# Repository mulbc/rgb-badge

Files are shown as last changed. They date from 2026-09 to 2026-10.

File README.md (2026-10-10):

<!-- SPDX-License-Identifier: CERN-OHL-S-2.0 -->

# RGB Badge

An open-source, full-colour wearable LED badge inspired by the FOSSASIA Badge Magic form factor.

The project is currently in **draft schematic development**. Several coupon circuits are captured, including a provisional charger core, but the complete power circuit and PCB are unfinished. No board in this repository has been independently reviewed, fabricated or tested. Do not treat current design material as production-ready.

## Product target

| Property | Target |
|---|---:|
| Display | 48 × 16 individually controlled RGB pixels |
| Pixel pitch | 1.95 mm |
| Finished envelope | ≤110 × 35 × 11 mm |
| Finished weight | ≤75 g target; 100 g absolute maximum |
| Reference runtime | Approximately 6 h at the defined mixed-content workload and fixed indoor brightness |
| Charging/data | USB-C, 5 V, A-to-C and C-to-C; native USB data |
| Wireless | BLE enabled only in programming mode |
| Controller | ESP32-S3-WROOM-1U-N16R8 |
| Manufacturing | Turnkey PCBA; no hand assembly of SMT parts |

Six hours is not a maximum-brightness guarantee. The initial model predicts about 6.3 hours with a 900 mAh cell for the reference workload and about 1.1 hours for continuous maximum full-screen white. Coupon measurements will replace those estimates.

## Development strategy

The first physical board is a production-intent 16 × 16 coupon. It compares Everlight `EAST10105RGBA0` 1010 and QT Brightek `QBLP1515A-RGB2A` 1515 common-anode RGB LEDs while exercising the intended controller, matrix driver, USB-C, charger, battery gauge, power converters, antenna and controls. The full 48 × 16 badge will not be ordered until the coupon passes its electrical, optical, thermal, runtime and RF acceptance tests.

Start with:

1. [Project context](CONTEXT.md)
2. [Requirements](docs/requirements.md)
3. [Full project plan](docs/project-plan.md)
4. [Accepted decisions](docs/decisions/README.md)
5. [Coupon core component candidates](docs/sourcing/coupon-rev-a-core-candidates.md)
6. [Contributor and agent rules](AGENTS.md)

## Repository layout

| Path | Contents |
|---|---|
| `docs/` | Requirements, decisions, project plan, bring-up and test evidence |
| `hardware/` | Editable KiCad projects and project-local libraries |
| `firmware/` | ESP-IDF firmware and host-side tests |
| `mechanical/` | Parametric enclosure source and reviewed exports |
| `manufacturing/` | Immutable, revisioned fabrication and assembly releases |
| `tools/` | Asset compiler, validation and release tooling |

## Safety and verification

This project contains a rechargeable lithium-polymer cell and switching power electronics. A completed coupon schematic and preliminary PCB layout must be reviewed by an experienced hardware engineer before fabrication. Battery charge limits may only be changed after checking the exact terminated-pack specification. Test results must always identify the board revision and must never be inferred or fabricated.

## Attribution

The project uses the [FOSSASIA Badge Magic hardware](https://github.com/fossasia/badgemagic-hardware) as an attributed reference. It is a new design rather than a copy of that PCB. See [NOTICE](NOTICE).

## Licensing

- Hardware design files, mechanical design files, manufacturing files and hardware documentation: [CERN-OHL-S-2.0](LICENSES/CERN-OHL-S-2.0.txt).
- Firmware, scripts and software tooling: [Apache-2.0](LICENSES/Apache-2.0.txt).
- Third-party files retain their original licences and must be recorded before inclusion.

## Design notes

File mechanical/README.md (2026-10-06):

<!-- SPDX-License-Identifier: CERN-OHL-S-2.0 -->

# Mechanical design

The enclosure will be parameterized in CadQuery and released as source plus reviewed STEP/STL exports. It must enforce the finished envelope, protect the pouch cell, reserve the RF zone and support a replaceable development diffuser.

Do not freeze the 900 mAh cell or final enclosure until a complete PCB STEP assembly proves the thickness stack without pouch compression.

The [2026-09-26 envelope screen](envelope-screen-2026-09-26.md) quantifies display width and a trial 11 mm thickness stack. It flags conflicting manufacturer length figures for the 900 mAh *bare* cell. Under [ADR 0019](../docs/decisions/0019-board-mounted-battery-temperature-sensing.md), a protected two-wire pack with a battery-facing PCB NTC is now allowed for testing; no final pack or physical fit is selected.

The [USB/LED edge screen](usb-led-edge-screen-2026-09-26.md) finds a nominal 0.025 mm copper intrusion into the USB cutout guide with the centred final LED grid and 106 mm board, and flags the connector's 0.80 mm board recommendation against the historical 1.0 mm plan. Actual placement and stack-up remain to be qualified.

The [preliminary front/rear placement study](preliminary-placement-screen-2026-09-26.md) additionally checks exact LED/USB courtyards. A centred grid conflicts with the USB courtyard; an illustrative 1.775 mm left shift avoids *bounding-box* intersections but does not establish manufacturability. The trial rear placement omits many components and the final battery.

The [2026-10-06 board/battery fit trial](fit-trial-2026-10-06.md) adds a grouped rear footprint plan and an 11 mm section with a separate LP503055 pack that still needs support above the board. All 32 row switches and 77 conditional under-pack 0402 candidates have nonoverlapping XY trial positions, but eight captured coupon parts and all remaining power/connector/RF/mounting needs are unplaced. A 0.55 mm 0402 height example leaves only 0.25 mm nominal case margin before assembly tolerances. No physical mount, complete PCB or DRC has been validated.

The [battery-connector screen](battery-connector-screen-2026-10-06.md) compares JST GH/PH and Molex PicoBlade families for the LP503055's bare AWG 28 wires. An illustrative PH mated pocket has no free position in the original grouped plan, even before small-part packing. No pack termination or polarity has been selected.

The [connector-first follow-on](connector-first-trial-2026-10-06.md) adds a compact Molex PicoBlade candidate and moves the switch, decoder and row FETs around its illustrative 8 × 8 mm pocket. It leaves 11 captured parts unplaced before the missing power hardware. The added connector is a geometric reservation, not a qualified footprint or selected pack termination.

The [dual-row package screen](dual-row-package-screen-2026-10-06.md) evaluates one complementary N/P MOSFET package per row under [proposed ADR 0020](../docs/decisions/0020-dual-row-mosfet-package-proposal.md). Its current XY trial accommodates the retained non-row captured parts, four power-IC package minima and the staged VLED passives; ADR 0021 removes the on-board battery-current monitor. Other support circuits, routing, copper and assembly clearances remain. It is not a complete PCB fit or an approved row-circuit change.

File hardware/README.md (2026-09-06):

<!-- SPDX-License-Identifier: CERN-OHL-S-2.0 -->

# Hardware

Editable KiCad electronics live here. Each revision is self-contained and must include project-local symbols, footprints and 3D models plus a README identifying its status and evidence.

The authoring baseline is KiCad 10.0.6 under [ADR 0006](../docs/decisions/0006-kicad-10-workflow.md). Use only validated stable `10.0.x` releases for canonical files; do not save them with a testing, nightly or newer major build.

Each revision will use this structure when capture begins:

```text
<revision>/
├── <project>.kicad_pro
├── <project>.kicad_sch
├── <project>.kicad_pcb
├── sym-lib-table
├── fp-lib-table
├── symbols/
├── footprints/<project>.pretty/
└── 3dmodels/
```

Before committing an exact part, compare symbol pin numbers, exposed pads, footprint geometry, courtyard, polarity/orientation marks and tape orientation with the current manufacturer documentation. Imported library models are starting material, not evidence of correctness.

No hardware design has been fabricated yet.

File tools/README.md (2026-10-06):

<!-- SPDX-License-Identifier: Apache-2.0 -->

# Software tools

The unlinked VLED converter is generated by tools/generate-coupon-vled.py and independently checked with native KiCad XML/ERC by tools/check-coupon-vled.py. The isolated sheet intentionally reports two missing source drivers; protected SYS and the display interlock are not captured.

`python3 tools/screen-preliminary-placement.py --output mechanical/review` reads four project-local footprint courtyards plus the USB cutout guide and regenerates the [final-badge bounding-box screen](../mechanical/preliminary-placement-screen-2026-09-26.md). It produces an SVG and JSON, **not** a KiCad PCB or DRC clearance. Its 700 mAh pack rectangle is a coupon-only mechanical comparison; no battery has been selected for the final badge.

**Current staged-gauge checkpoint — ADR 0015:** `generate-coupon-gauge.py --output NEW_DIRECTORY` produces the gauge/bypass/two pull-ups and a flagged **assumed** switched battery boundary without replacing canonical source. `check-coupon-gauge.py` checks exact part metadata and source pin nets; the complete KiCad XML check now expects **400 on-board items and 1,507 logical pins**, including the new alert no-connect. Native KiCad review is pending, and no physical battery, charger or latching switch is captured. [Boundary record](../hardware/coupon/rev-a/switch-gauge-boundary.md). The previous ADR 0013 Type-C-only checkpoint had 396 items / 1,492 pins; its 16-state permission and independent gate checks still run. Older dual-limit/BC1.2 calculations are historical.

`generate-coupon-permission.py --output NEW_DIRECTORY` produces the conditioning and permission sheets without overwriting canonical files. `check-coupon-permission.py` traces 61 items / 176 pins and evaluates actual gate connections against the independent 1,024-state contract. This checkpoint passed native review at `6d9a08b`.

`generate-coupon-usb.py --output NEW_DIRECTORY` produces the USB interface sheet. `check-coupon-usb.py` checks its 20 items / 84 logical pins and domain/data connections. The added logic supervisor brings complete XML validation to **443 items / 1,636 logical pins**. Native review at [2bb0e08](../docs/development/logic-supervisor-review-2bb0e08.md) passed zero ERC violations and the eleven-page export. The precision-resistor increment added three ERA2 symbols and one footprint. The subsequent candidate ADG4612 library brings exports to **46 symbols and 27 footprints per raw view**; its [native rendering at 2b7a468](../docs/development/actuator-library-review-2b7a468.md) passed. Its [native rendering at 9e71bb5](../docs/development/precision-resistor-review-9e71bb5.md) passed; older counts below are historical.

`check-programming-resistors.py` validates the exact ADR 0012 symbols, ERA2 lands/courtyard and conditional multiplicative error budget. The existing current ceilings retain ±1% total resistance error. The assembly/service drift allocation, switch leakage and complete USB-current budget remain qualification items. `check-kicad.sh` requires each new native export; test fixtures only exercise wrapper behavior.

The [permission-library audit](../hardware/coupon/rev-a/permission-library-audit.md) covers the six new exact gate/supervisor symbols and shared DBV5/DBV6 package checks. `check-power-libraries.py` now guards ground-pin differences, open-drain electrical types, output polarity, package body/courtyard geometry and DBV6 mask/paste settings. Native permission-library rendering passed at `6d9a08b`; TPS3808 is now captured as U34 and passed native review at 2bb0e08.

Host-side utilities will include the deterministic content compiler, schema validation, release-manifest generation and analysis of power/runtime logs. Tools must be testable without a connected badge and must not rewrite measured evidence.

`check-led-libraries.py` audits the exact Coupon Rev A LED symbol pin maps, source drawing layout, footprint pads, polarity geometry and the nominal 1.95 mm checkerboard-clearance calculation. `check-kicad.sh` runs that audit, loads and exports the project-local libraries through KiCad 10, and runs schematic ERC. `check-erc-report.py` requires zero ERC messages; the historical `USB_D-` / `USB_D+` boundary exceptions are retired. Raw fabrication views and solid copper-only views are exported into separate directories.

`number-footprint-review.py SOURCE.svg NEW_OUTPUT.svg` creates a separate numbered review copy of a four-pad KiCad 10 fabrication export. It overlays KiCad's own glyph paths on white halos so body lines do not obscure the pad numbers. It preserves source evidence and geometry, adds a viewing margin, records the source SHA-256, and fails if the expected label structure changes. With `--profile rpw`, it requires the exact 14-glyph/10-pad multiplicities, removes numeric glyphs only from the derived copy and overlays the first unchanged source glyph per pad. This resolves repeated corner numbers on the compound RPW lands without moving geometry. The wrapper places these derived files in `footprints/numbered/`; they are not manufacturing outputs. The [recorded review](../docs/development/led-library-review-27c01b4.md) used the owner's actual KiCad exports.

`check-coupon-matrix.py` checks the matrix source: it verifies cached symbols, traces short wires to global labels, and checks all 256 LEDs and 1,024 pin-to-net assignments. This source subset checker is not KiCad ERC and does not support arbitrary buses, rotations or mid-wire junctions. Its historical `--netlist` mode remains available for matrix-only fixtures; the controller checker now owns complete native XML validation. `check-kicad.sh` runs every source checker around the real KiCad ERC/netlist export and also exports `coupon-schematic.pdf`.

`generate-coupon-matrix.py --output NEW_DIRECTORY` reproduces the initial matrix capture with stable UUIDs. It writes only a new directory and refuses existing paths. The generated draft was reviewed before its files were copied into the canonical project. Do not regenerate over subsequent KiCad edits; compare a temporary regeneration and integrate deliberate changes. Schematic orientation does not set PCB placement rotation.

Run the wrapper regression tests without KiCad:

```bash
python3 -m unittest discover -s tools/tests -p 'test_*.py' -v
```

The wrapper tests use a stub executable to check CLI arguments, output separation and failure handling. SVG-helper tests check original-geometry and glyph preservation, rejection of missing/duplicate/transformed labels, and protection against overwriting evidence. They do not render KiCad files, run real ERC, prove legibility or approve hardware. Actual KiCad output and human inspection remain required.

Matrix regression tests deliberately inject a colour swap with unchanged net sizes, a missing LED, a short between columns, a duplicated pin, a wire endpoint that misses its LED pin, and a global label facing into its wire. The label-direction check came from actual PDF review at `7120e93`. Synthetic XML tests prove checker behaviour; only a real KiCad-exported netlist can verify KiCad's interpretation of the new schematic.

## Driver increment

`python3 tools/check-coupon-driver.py` checks the controlled driver/support library, footprint geometry and simple source wiring. Its `--netlist` mode preserves the historical matrix-plus-driver 1,094-pin contract for regression evidence. The full current project must use `check-kicad.sh`, which delegates the complete XML to the row checker.

`python3 tools/check-row-libraries.py` independently checks the exact row decoder, P/N MOSFET and 1 kΩ pull-up symbols against their manufacturer pin tables, plus the TSSOP24, SC-59 and SOT23 pad geometry.

`python3 tools/check-coupon-rows.py` traces the captured decoder, all sixteen P/N-MOS stages, 37 resistors, decoupling and draft VLED boundary. Its `--netlist` mode preserves the historical 335-item / 1,290-pin matrix + driver + row contract. `generate-coupon-rows.py --output NEW_DIRECTORY` deterministically reproduces the initial row sheet and refuses existing paths; never regenerate over canonical KiCad edits.

`python3 tools/check-controller-libraries.py` checks the exact N16R8 module symbol/pad map, reset/USB/UART passives, capacitor lands and duplicate-contact mode-button footprint. `python3 tools/check-coupon-controller.py` traces the controller source and explicit no-connects; its `--netlist` mode owns the complete current contract; the original controller-stage contract was 356 items / 1,360 logical pins. `generate-coupon-controller.py --output NEW_DIRECTORY` deterministically reproduces the initial controller sheet and refuses existing paths.

The wrapper exports all project-local symbols and footprints, including separate paste views, and requires their files to be nonempty. `coupon-matrix.xml` retains its historical filename but contains the whole captured schematic. Local fixture tests do not run KiCad. Follow the [controller review instructions](../hardware/coupon/rev-a/controller-capture.md#native-review-still-required) for the current eight-page circuit.

`generate-coupon-matrix.py` is the historical one-time matrix-only capture helper. It must not replace the current root schematic: that would remove the driver sheet. The current KiCad files are canonical.

## Power pre-capture

`python3 tools/check-usb-connector.py` checks the GCT USB4505 candidate's 16-contact/12-land mapping, four plated shell-slot interpretations, 0.20 mm nominal copper clearance and non-manufacturing cutout datums. `check-kicad.sh` also exports a separate `footprints/mechanical/` view. See the [connector audit](../hardware/coupon/rev-a/usb-connector-audit.md) for source evidence, native review status and the unresolved cutout relief/process limits. The connector is not yet instantiated.

`python3 tools/check-power-design.py` freezes the selected BQ24074 `ISET`/external-`ILIM` arithmetic, ADR 0010 source/switch/configuration/suspend state table, initial TPS631000/TPS63020 feedback dividers, and maximum charger-plus-gauge allocation within the 50 uA OFF-state budget. It deliberately does not approve the captured BQ24392/TS3USB31E/priority logic as a complete power system, VBUS auxiliary-current budget, pack-dependent NTC/current limit, linear thermal behavior, converter passives or layout. See the [power/input pre-capture record](../hardware/coupon/rev-a/power-pre-capture.md).

`python3 tools/check-power-libraries.py` checks the selected `BQ24074RGTR`, `BQ24392RSER`, `TS3USB31ERSER`, legacy `BQ25616JRTWT`, `TPS631000DRLR`, `TPS63020DSJT`, `TLV75533PDBVR`, `SN74LVC1G04DBVR`, `MAX17048G+T10`, `INA232AIDDFR`, base-suffix `TPD4E05U06DQAR` and `TUSB320LAIRWBR` symbols against manufacturer pin tables. It verifies every RGT/RSE/RTW/DRL/DSJ/DBV/DDF/DQA/RWB/T822+3 land, exposed-pad splits, the RWB side-pad copper/paste difference, layers and pin-1 marks. The [power-library audit](../hardware/coupon/rev-a/power-library-audit.md) records source hashes and the intentionally unresolved connector/control packages. `check-kicad.sh` requires nonempty native symbol plus fabrication/copper/paste exports for every new footprint; the selected replacement libraries passed [native render review at c054cb4](../docs/development/power-replacement-review-c054cb4.md). Their [audit](../hardware/coupon/rev-a/power-replacement-library-audit.md) records the narrower RSE middle pads, 0.05-mm radii, body axes and corresponding fault tests.

`python3 tools/check-usb-permission.py` checks ADR 0011's detector GPIO contract over 1,024 stable input combinations, including hardware-only resistor boost and default-deny supply/reset behavior. This is a static contract, not a captured or simulated gate circuit. The power arithmetic check reserves configured-SDP auxiliary headroom, rejects the historical fixed-USB500 budget and prints the remaining capture blockers explicitly. Run `python3 tools/check-power-design.py --require-usb-closure` to require an implemented USB topology: it still exits 1 by design until protected input, supervisors, charger/ILIM actuation and complete power qualification are finished. State-table or library success alone is not USB-current closure. The rejected BQ25616J arithmetic remains as regression evidence.

## Logic-rail supervision checkpoint

`check-usb-supervision.py` audits the TPS3808 divider/CT selection and exact 620 kohm resistor. It is called by the permission capture check. Source totals are now 443 items / 1,636 logical pins on eleven pages. The native d502e65 bundle passed ERC/XML; its two heading findings and the added supervisor passed native review at 2bb0e08. See [capture and limits](../hardware/coupon/rev-a/usb-supervision-capture.md). The ordinary-resistor temperature counterexample remains regression evidence; ADR 0012 precision selection addresses it conditionally, with assembly/service drift still requiring qualification.

`check-power-design.py` also reports the candidate actuator shared-rail static UVLO margin. `actuator_supply_screen()` accepts explicit hypothetical local-drop/slew/delay bounds; it is a sensitivity calculation, not a transient guarantee. See the [supply analysis](../hardware/coupon/rev-a/charger-actuator-supply-analysis.md).

## Input protection screening

`python3 tools/check-input-protection.py` calculates candidate OVLO and PGTH divider corners with signed leakage and total resistor error, and records fixed-clamp/current-threshold limitations. It does not select a protection IC or validate transients. `--require-closure` deliberately fails until the input circuit is qualified. See ADR 0014 and `hardware/coupon/rev-a/usb-input-protection-screening.md`.

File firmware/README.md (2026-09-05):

<!-- SPDX-License-Identifier: Apache-2.0 -->

# Firmware

Production firmware will use ESP-IDF and native C/C++. Initial scope is hardware validation: deterministic matrix scan timing, safe rail defaults, USB diagnostics, telemetry, test patterns, button state handling and a minimal BLE programming-mode transfer.

Host-test asset parsing, gamma conversion, frame scheduling and runtime-estimator maths before relying on target hardware. Do not create production drivers until exact devices and the machine-readable board pin map are frozen.

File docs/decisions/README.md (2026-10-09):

<!-- SPDX-License-Identifier: CERN-OHL-S-2.0 -->

# Architecture decision records

Decision records explain choices that materially constrain later work. Accepted records are not silently rewritten when a decision changes: add a superseding record and update the affected requirements and project context.

| ADR | Decision | Status |
|---|---|---|
| [0001](0001-coupon-first-development.md) | Validate a production-intent coupon before the full badge | Accepted |
| [0002](0002-discrete-multiplexed-rgb-matrix.md) | Use a discrete multiplexed RGB matrix | Accepted |
| [0003](0003-esp32-s3-module-and-external-antenna.md) | Use ESP32-S3 N16R8 with an external antenna | Accepted |
| [0004](0004-standalone-charging-and-hard-off-state.md) | Use standalone charging and switched application rails | Input-current proposal superseded by ADR 0009; functional requirements retained |
| [0005](0005-project-licensing.md) | Use CERN-OHL-S for hardware and Apache-2.0 for software | Accepted |
| [0006](0006-kicad-10-workflow.md) | Target KiCad 10 stable with controlled upgrades | Accepted |
| [0007](0007-coupon-led-finalist-pair.md) | Populate the coupon with two final-product LED candidates | Accepted |
| [0008](0008-qblp1515-checkerboard-placement.md) | Preserve the QBLP1515 land pattern with checkerboard rotation | Accepted |
| [0009](0009-usb-input-current-closure.md) | Reject unqualified direct USB input-current network | Accepted constraint; replacement selected by ADR 0010 |
| [0010](0010-source-qualified-off-charging.md) | Charge while OFF only from a qualified source | Accepted for capture; thermal/Gate A pending |
| [0011](0011-usb-total-current-headroom.md) | Reserve current for USB detection and permission logic | Accepted; resistor specification amended by ADR 0012 |
| [0012](0012-programming-resistor-error-budget.md) | Include temperature and drift in programming-resistor limits | Exact parts selected; assembly/service qualification pending |
| [0013](0013-type-c-only-fixed-current-charging.md) | Use Type-C-only charging with a fixed limit | Accepted for coupon capture; hardware verification pending |
| [0014](0014-usb-voltage-envelope-and-logic-ldo.md) | Correct USB voltage envelope and logic regulator | Draft circuit reviewed; input-stage qualification pending |
| [0015](0015-switch-fuel-gauge-with-application.md) | Disconnect the gauge with the physical switch | Accepted for coupon capture; exact switch and SOC recovery validation pending |
| [0016](0016-runtime-and-fit-over-charge-speed.md) | Prioritize badge runtime and fit over charging speed | Accepted; exact terminated pack and charge times pending |
| [0017](0017-parallel-3v3-converter-capacitors.md) | Parallel exact capacitors on the coupon application converter | Provisional coupon target; complete derating and rail qualification pending |
| [0018](0018-complete-power-architecture-proposal.md) | Review the complete power topology as one functional block | Proposed; six capture holds, no circuit changes |
| [0019](0019-board-mounted-battery-temperature-sensing.md) | Trial a board-mounted battery temperature sensor with protected two-wire packs | Accepted direction; cell-to-board thermal validation pending |
| [0020](0020-dual-row-mosfet-package-proposal.md) | Evaluate one complementary N/P package per row to recover PCB area | Proposed; no schematic or BOM change |
| [0021](0021-external-battery-current-measurement.md) | Measure battery current with an inline instrument during validation; omit the on-board monitor/shunt | Accepted for capture; instrument/harness and hardware validation pending |
| [0022](0022-lower-fixed-usb-input-limit-proposal.md) | Evaluate one existing 3.65 kΩ ILIM resistor to simplify charger/eFuse current coordination | Proposed; no schematic or BOM change |
| [0023](0023-charger-en2-local-clamp-proposal.md) | Feed charger EN2 from admitted input through a local 2.5 V clamp | Proposed; transient and EN2-load checks pending |
| [0024](0024-lp452845-pack-and-temperature-window.md) | Design Rev A around the exact protected LP452845/PHR-2 assembly with NTC and buffered hardware temperature inhibit | Accepted design target; source capture and physical qualification pending |

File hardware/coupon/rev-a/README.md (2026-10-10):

<!-- SPDX-License-Identifier: CERN-OHL-S-2.0 -->

# Coupon Rev A

**2026-10-06 VLED increment:** An [unlinked, default-disabled converter candidate](vled-converter-capture-contract.md) now captures the TI LED buck-boost, exact passives and local switching nodes. A separate [native local placement trial](staging/vled-layout-trial.kicad_pcb) carries the thirteen exact project footprints and schematic pad nets, with no routing or full-board DRC. It does not close the SYS source or display-interlock holds and is not a fabrication release.

**2026-10-10 power direction:** [Complete power system](../../../docs/design/power-architecture-2026-10-05.md), with [proposed ADR 0018](../../../docs/decisions/0018-complete-power-architecture-proposal.md), consolidates topology choices, budgets and six capture holds. [ADR 0024](../../../docs/decisions/0024-lp452845-pack-and-temperature-window.md) selects the exact protected `LP452845`/`PHR-2` finished assembly as the Rev A design target. The battery-facing NTC and separate TMP390 hot/cold hardware-inhibit subcircuit are now on a [root-linked sheet](charger-temperature.kicad_sch); its `CHARGER_TS` and `CHARGER_GATE_EN` nets await the BQ24074 and E1 connections. The pack connector is also not yet captured. Native KiCad exports can be run locally by the assistant.

The [TMP390 first-author library](tmp390-library-audit.md) maps the selected IC's six pins to a project-local DRL0006A footprint. The [connected temperature-sheet review](../../../docs/development/charger-temperature-capture-review-2026-10-10.md) records the source, native XML/ERC and visual checks. It does not demonstrate temperature protection on hardware.

The selected JST `S2B-PH-SM4-TB` board-header land is now staged in the [project-local footprint library](jst-ph-header-library-audit.md). Contact 1/2 and the retention lands are audited and rendered, but the header has no root schematic connection until the exact finished pack's lead polarity is reconciled with the mating view.

**Provisional application-power capture, 2026-10-05:** The [JS202011JCQN library audit](slide-switch-library-audit.md) now accompanies a root-linked control pole and the existing TPS631000 3.3 V converter candidate. The old `+3V3_APP` source flag is removed; the converter output is the schematic source. `+SYS_APP_IN_DRAFT` still has an explicit source flag because the charger/pack path is not captured. Switch pole 2 and the gauge source flag remain untouched pending bus isolation. JCQN is not yet the final top-edge mechanical selection. Native KiCad 10.0.6 ERC, complete XML and visual page review passed for the provisional sheets; no board or electrical hardware test exists.

**Active revision: [ADR 0013](../../../docs/decisions/0013-type-c-only-fixed-current-charging.md).** Type-C-only charging, one fixed current limit; no BC1.2 or firmware charge grants. The revised USB source has 396 total PCB items / 1,492 logical pins and eleven pages; [native ERC/XML and three-sheet visual review passed at 12a134f](../../../docs/development/type-c-only-review-12a134f.md). Libraries remain 46 symbols / 27 footprints. See [simplified capture](type-c-only-capture.md); earlier counts and source-policy descriptions below are historical.

**Follow-on draft:** [ADR 0014](../../../docs/decisions/0014-usb-voltage-envelope-and-logic-ldo.md) changes U29 to TPS70933DBVR and intentionally opens EN. Counts remain 396 items / 1,492 pins; libraries are now 47 symbols / 27 footprints. Native U29 review passed at bad43fa; see [evidence](../../../docs/development/input-review-bad43fa.md). No repeat run is needed; [source audit and screening](usb-input-protection-screening.md).

**Candidate input libraries:** [RPW0010A audit](input-protection-library-audit.md) adds TPS259472ARPWR and TPS259474ARPWR, neither placed or selected. Current exports: 49 symbols / 28 footprints. Circuit counts are unchanged; native candidate symbol/copper/paste review passed at bad43fa. The derived RPW numbering view resolves the compound-corner label overlap.

Status: matrix, driver, row-stage and controller staged electrical reviews passed; power-library copper/stencil/heading corrections passed native review at `3638b1d`. The row-page readability repair passed [native review at `91ef697`](../../../docs/development/layout-review-91ef697.md), and the USB4505 candidate library passed [native rendering review at `bf1627c`](../../../docs/development/usb-connector-review-bf1627c.md). Remaining power capture and independent Gate A verification are pending; not safe to fabricate. See the [finding record](../../../docs/development/power-library-review-c84f8ce.md).

## Purpose

Validate the production electrical architecture and compare 1010 versus 1515 RGB LEDs before scaling to the 48 × 16 badge.

The provisional direct input-current network is rejected by [ADR 0009](../../../docs/decisions/0009-usb-input-current-closure.md). [ADR 0010](../../../docs/decisions/0010-source-qualified-off-charging.md) selects BQ24074/BQ24392/TUSB320/TS3USB31E for the next power capture, with standby as the fail-safe state, OFF charging limited to hardware-qualified sources and a switched-rail second data switch for hard-OFF isolation. The [assessment](usb-input-assessment.md) records its state table and missing proof. Exact replacement libraries pass host audits and [native rendering review at c054cb4](../../../docs/development/power-replacement-review-c054cb4.md); [ADR 0011](../../../docs/decisions/0011-usb-total-current-headroom.md) now reserves configured-SDP auxiliary headroom using low external ILIM and a hardware-only resistor boost. Its static GPIO permission checks pass; detector/logic source capture is present, while startup inhibition, remaining power capture and thermal validation are pending.

## Required contents

The [permission capture](permission-capture.md) passed [native review at 6d9a08b](../../../docs/development/permission-review-6d9a08b.md), including all seven new symbols and corrected DBV5/DBV6 views. The [USB interface capture](usb-interface-capture.md) now connects the detectors, data path and USB-only LDO. It adds 20 items / 84 logical pins and two exact resistor symbols, with no new footprint. Complete source has eleven pages and 437 items / 1,620 logical pins. [Native ERC/XML at d502e65 passed](../../../docs/development/usb-interface-review-d502e65.md); two heading overlaps were corrected and closed by native review at 2bb0e08. ERC requires zero violations. The follow-on [logic supervisor](usb-supervision-capture.md) adds six items / sixteen pins: current totals are 443 items / 1,636 pins, still eleven pages. Its native ERC/XML and visual review passed at 2bb0e08.

The connector VBUS and the staged +5V_USB supply are deliberately separate until input protection is designed. VBUS qualification, physical startup inhibition, charger/ILIM actuation and remaining power sources are still open; the logic-rail supervisor is captured. #FLG04 was removed; #FLG05 marks the unfinished protected-input boundary; #FLG06 annotates power after the detector ballast resistor for ERC.

- 16 × 16 pixels at 1.95 mm pitch: columns 0–7 use Everlight `EAST10105RGBA0`; columns 8–15 use QT Brightek `QBLP1515A-RGB2A`.
- ESP32-S3-WROOM-1U-N16R8 and external antenna.
- One TLC59581 and all sixteen level-shifted row stages.
- Production USB-C, ESD, Type-C detection and standalone charger circuits.
- Production 3.3 V/VLED converters, fuel gauge, NTC interfaces and controls; battery-current measurements use an external inline instrument under ADR 0021.
- Native USB diagnostics and hidden factory programming/test pads.

The exact draft candidates and open circuit risks are tracked in the [Coupon Rev A sourcing record](../../../docs/sourcing/coupon-rev-a-core-candidates.md). The [Panasonic order-code audit](panasonic-order-code-audit.md) records the corrected ERJ2 identities and outstanding native roundtrip. A candidate in that record is not an approved purchase or fabrication BOM line.

The [charger thermal sensitivity screen](charger-thermal-screen.md) compares existing worst-corner ISET cases with TI's RGT reference-board thermal metric at 5.5 V. It flags thermal regulation risk for the old 0.872 A draft even in display-OFF charging; it does not select a resistor or establish actual enclosure temperature.

The [September 27 exact-pack shortlist](../../../docs/sourcing/pack-shortlist-2026-09-27.md) narrowed the US-stocked 700 mAh pack to conditional coupon use and treated a thin 900 mAh two-wire LiPol listing as a manufacturer inquiry. [ADR 0016](../../../docs/decisions/0016-runtime-and-fit-over-charge-speed.md) permits a slower safe charge to prioritize runtime and fit. Do not freeze ISET or a battery connector from those listings alone.

[ADR 0019](../../../docs/decisions/0019-board-mounted-battery-temperature-sensing.md) permits trialing a battery-facing PCB NTC with a protected two-wire pack. The [October 5 sourcing screen](../../../docs/sourcing/pack-screen-2026-10-05.md) and [October 9 mechanical swap](../../../mechanical/lp452845-swap-screen-2026-10-09.md) now support the connectorized `LP452845` design target. Its 900 mA discharge statement is not explicitly continuous, stock is unconfirmed and the thermally coupled NTC/TMP390 arrangement still needs physical qualification. The old bare-wire `LP503055` remains a comparison option.

The [MAX17048 capture contract](fuel-gauge-capture-contract.md) implements the [ADR 0015](../../../docs/decisions/0015-switch-fuel-gauge-with-application.md) decision to disconnect gauge power with the physical switch while keeping autonomous OFF charging. A [staged gauge sheet](switch-gauge-boundary.md) places the gauge, bypass and exact 2.2 kΩ pull-ups. Its switched-BAT supply uses a clearly labeled draft PWR_FLAG: the real switch, charger and protected pack remain uncaptured. The [corrected native review at d9d717a](../../../docs/development/gauge-review-d9d717a.md) passed configured ERC, XML and page-12 visual inspection. Bus timing, OFF leakage and post-charge SOC recovery require verification.

The [3.3 V converter capture contract](3v3-converter-capture-contract.md) records TI's TPS631000 starting circuit, pin-level switch/rail defaults and voltage-tolerance arithmetic. An [unlinked candidate sheet](staging/README.md) now captures nine exact-MPN items and local LX nodes for source review; it is not part of the root/ERC/netlist. [ADR 0017](../../../docs/decisions/0017-parallel-3v3-converter-capacitors.md) sets a provisional coupon target of two exact Murata input and two exact Murata output capacitors to increase effective-capacitance margin. The [first-author capacitor library audit](3v3-capacitor-footprint-audit.md) reuses the GRM18 0603 land and stages a GRM21 0805 land and two exact-MPN symbols; [KiCad export and first-author visual review at 8014947](../../../docs/development/3v3-passive-library-review-8014947.md) passed. The [inductor land audit](3v3-inductor-footprint-audit.md) stages the exact Murata 1 µH library, with native rendering pending. Current capacitor approval, combined temperature/aging proof, placement and startup response remain open. The protected SYS source, latching switch and root-linked converter sheet still require capture and review. The battery inquiry does not block this preparatory work.

## Open and validate

Follow the [macOS KiCad setup and round-trip check](../../../docs/development/kicad-macos.md). The canonical project entry point is `rgb-badge-coupon.kicad_pro`. Run `../../../tools/check-kicad.sh` from this directory, or `./tools/check-kicad.sh` from the repository root.

The root now links four matrix sheets, the TLC59581 driver, the [sixteen-row selector sheet](row-capture.md) and the [ESP32-S3 controller sheet](controller-capture.md). The matrix/driver native run at `8e95eb0` passed all 1,094 then-captured physical pins and six-page visual review. The [row library audit](row-library-audit.md) and [native rendering review](../../../docs/development/row-library-review-0c71860.md) control the decoder/MOSFET libraries. The row source includes U2, C2, all 32 MOSFETs and 37 resistors; the native run at `eb4129b` passed zero-violation ERC, all 335 PCB items / 1,290 physical pins and seven-page visual review. The [review record](../../../docs/development/row-capture-review-eb4129b.md) preserves that evidence. Controller source adds U3, reset/mode networks, native USB/UART boundaries and eleven hidden test pads; the [native controller review](../../../docs/development/controller-review-d56e1aa.md) passed the exact temporary USB-boundary warning pair, all 356 PCB items / 1,360 logical pins, footprint renders and eight-page visual review. The [power-library audit](power-library-audit.md) adds machine-checked exact symbols and manufacturer land patterns for the charger, both switched converters, USB-only LDO/inverter, Type-C detector, fuel/current monitors and USB ESD array; corrected native rendering passed at `3638b1d`. The recovered [USB4505 candidate-library audit](usb-connector-audit.md) controls the separate connector symbol and draft footprint; host and [owner-generated native rendering checks](../../../docs/development/usb-connector-review-bf1627c.md) pass, while cutout reliefs and mechanical/process qualification remain pending. The new USB interface sheet supersedes the earlier connector/data boundary. Input protection, charging, gauging and switched power sources are not captured; #FLG01–#FLG03 and #FLG05 remain explicit draft supply assumptions; no PCB exists.

The two project-local LED symbols and footprints completed the first-author [LED audit](footprints/led-audit.md) and rendering review. Independent verification remains pending. The earlier macOS blank-sheet ERC result does not validate this new circuit.

## Release blockers

- Controlled LED datasheets; verified footprints, pad numbering, polarity, tape orientation and optical-bin procurement.
- Confirm supplied TLC59581 E/G package variant, current-limit accuracy/derating and remaining driver layout/thermal checks.
- Exact battery-pack documentation.
- Audited BQ24074/BQ24392/TS3USB31E libraries and reviewed priority/level logic for USB default-current, BC1.2, Type-C advertisement and native-data coexistence in switch-ON and switch-OFF states.
- Completed calculations, schematic and ERC.
- Preliminary placement/routing and DRC/DFM.
- Independent engineer review with every finding resolved or explicitly accepted.

The intended first order is five PCBs with three assembled. That order is not authorized by this README.

## Precision programming resistors

The [2bb0e08 native review](../../../docs/development/logic-supervisor-review-2bb0e08.md) accepted the logic supervisor and corrected USB headings. [ADR 0012](../../../docs/decisions/0012-programming-resistor-error-budget.md) now selects exact 0.1%, 25 ppm/K ILIM/ISET parts without changing the nominal values or current ceilings. Their [library audit](programming-resistor-audit.md) covers the new ERA2 land pattern and conditional total-error budget. [Native rendering at 9e71bb5](../../../docs/development/precision-resistor-review-9e71bb5.md) passed; that checkpoint contained 45 symbols / 26 footprints. Circuit counts remain 443 items / 1,636 pins over eleven pages. Charger, actuation, input protection and remaining power capture are still open.

Next: [charger actuator screening](charger-actuator-screening.md). ADG4612BCPZ-REEL7 is an investigated candidate, not a selected or captured part; its supplied PDF has been reviewed and its [candidate library](charger-actuator-library-audit.md) passed [native rendering at 2b7a468](../../../docs/development/actuator-library-review-2b7a468.md). Current libraries contain 46 symbols / 27 footprints. The lands are project-derived and require assembler qualification.

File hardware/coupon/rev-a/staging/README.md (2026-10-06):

<!-- SPDX-License-Identifier: CERN-OHL-S-2.0 -->

# Unlinked 3.3 V application converter candidate

The separate [VLED converter candidate](../vled-converter-capture-contract.md) now stages thirteen exact-MPN items in vled-converter.kicad_sch. It is default-disabled and remains unlinked until protected SYS and the hardware display interlock are captured.

The separate [VLED local layout trial](vled-layout-trial.kicad_pcb) uses the same thirteen project-local footprints and their exported schematic pad nets at the coordinates of the [lower-right cluster screen](../../../../mechanical/dual-row-package-screen-2026-10-06.md). It has a local study outline, no tracks, vias or copper zones, and none of the neighbouring final-board circuitry. Generate and round-trip-check it with KiCad's bundled Python: `/Applications/KiCad/KiCad.app/Contents/Frameworks/Python.framework/Versions/3.9/bin/python3 tools/generate-vled-layout-trial.py`. KiCad 10.0.6 loaded and plotted its actual pads. [Native local-board DRC evidence](../../../../docs/development/vled-layout-trial-2026-10-06.md) records zero geometric violations and thirty expected open connections when run with desktop access. This is not a routed/full-board DRC pass. This file is a placement study, never a fabrication source.

`3v3-converter.kicad_sch` contains the exact `TPS631000DRLR`, one Murata `DFE252012P-1R0M=P2` 1 µH inductor, two `GRM187R61A226ME15` input capacitors, two `GRM219R60J476ME44` output capacitors, the Panasonic 511 kΩ / 91 kΩ feedback pair, and a 100 kΩ EN pull-down. The source checker verifies nine items, all 24 pins and the two *local* LX switching nodes. Regenerate deterministically into a new directory with `python3 tools/generate-coupon-3v3.py --output /tmp/rgb-3v3-candidate`; compare with this source before replacing it.

This historical candidate remains **unlinked** for deterministic comparison. A distinct, root-linked copy now exists at `../3v3-converter.kicad_sch` with SW2's first control pole on EN; the previous `+3V3_APP` draft source flag was removed. `+SYS_APP_IN_DRAFT` remains a flagged, unresolved charger/pack source. `APP_3V3_FB` is a schematic feedback net, not a routed board design. The battery pack, charger, gauge pole, LED supply and whole-board OFF leakage remain uncaptured or unqualified.

The [capture contract](../3v3-converter-capture-contract.md) records the TI starting circuit, conditional capacitor choice and load/current sensitivity. The [inductor audit](../3v3-inductor-footprint-audit.md) and capacitor/feedback audits control the libraries. [Native XML and visual review at c929711](../../../../docs/development/3v3-candidate-review-c929711.md) confirms all 24 connections and identifies two presentation repairs, now source-corrected but awaiting the next combined export. No candidate ERC report was supplied; the main project's passing ERC does not validate it. Integrate only after the protected SYS and switch boundaries are reviewed, then remove the superseded flags, run native ERC/netlist and inspect the page, and update the whole-project checker. This is not a fabrication release.

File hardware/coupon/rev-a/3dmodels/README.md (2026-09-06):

<!-- SPDX-License-Identifier: CERN-OHL-S-2.0 -->

# Coupon project-local 3D models

Store reviewed STEP models used by Coupon Rev A here. Record the source, licence, exact MPN and dimensional cross-check for every imported model. A model is visual/mechanical evidence only; it does not validate a symbol or footprint.

This directory is intentionally empty at scaffold creation.

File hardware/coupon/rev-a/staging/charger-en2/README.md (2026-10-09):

<!-- SPDX-License-Identifier: CERN-OHL-S-2.0 -->

# Unlinked charger EN2 candidate

This two-part [KiCad schematic](charger-en2-candidate.kicad_sch) is the isolated ADR 0023 mode-source candidate. Run `tools/generate-coupon-charger-en2.py` from the repository root to regenerate its schematic and combined local symbol library. It does not include or control E1 or BQ24074, and does not make the coupon charger functional.

`LM4040A25IDBZT` is TI's active A-grade 2.5 V, industrial-temperature DBZ SOT-23-3 orderable. [TI Rev Q](https://www.ti.com/lit/ds/symlink/lm4040.pdf) Table 5-1 maps cathode pin 1, anode pin 2 and optional pin 3. Pin 3 is grounded here, as TI permits and recommends near switching noise. The candidate footprint transcribes TI DBZ0003A's 3 × 0.6 × 1.3 mm lands, paired pads at ±0.95 mm from the centerline and 2.1 mm row separation. Board-top pads 1/2 are the pair; pad 3 is opposite. The 0.05 mm rounded corners and marker are candidate geometry. Exact land/polarity orientation must receive independent visual review before it moves to the canonical library or a board.

`ERJ2RKF1002X` is Panasonic's exact 10 kΩ ±1%, 0402, 0.1 W part; its existing project-local symbol and land were copied into this isolated library. [Panasonic model page](https://industrial.panasonic.com/ww/products/pt/general-purpose-chip-resistors/models/ERJ2RKF1002X). No new accepted BOM population follows from the copy.

On 2026-10-07, KiCad CLI 10.0.6 exported an XML netlist: R88.1 = `CHARGER_IN`; R88.2 = U38.1 = `CHARGER_EN2`; U38.2 and U38.3 = ground. ERC reported zero errors and one expected isolated-input-label warning. That check establishes source connectivity only, not EN2 current, startup timing, resistor temperature, input protection or hardware behavior. Independent Gate A remains required before fabrication.

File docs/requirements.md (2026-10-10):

<!-- SPDX-License-Identifier: CERN-OHL-S-2.0 -->

# Product requirements

Status: Baseline accepted; measurements pending
Source: requirements interview completed 2026-09-05

“Coupon” means the production-intent 16 × 16 validation board. “Final” means a complete cased 48 × 16 badge.

| ID | Requirement | Verification | Applies to |
|---|---|---|---|
| DSP-001 | Provide 48 × 16 individually controlled RGB pixels. | Design inspection and pixel self-test | Final |
| DSP-002 | Pixel pitch shall be no greater than 1.95 mm; baseline is exactly 1.95 mm. | PCB dimension inspection | Coupon/final |
| DSP-003 | Accept 24-bit source art and apply gamma and programmable white balance. | Golden-image firmware test and visual test | Coupon/final |
| DSP-004 | Support 60 content-frame updates per second and at least 1 kHz visual refresh. | Logic trace and camera test | Coupon/final |
| DSP-005 | Brightness shall remain at the user-programmed fixed value during normal playback. | Runtime state/telemetry test | Coupon/final |
| DSP-006 | Safety logic may disable the display on an electrical or thermal fault, but shall not silently dim it. | Fault-injection test | Coupon/final |
| DSP-007 | Coupon columns 0–7 shall use `EAST10105RGBA0` and columns 8–15 shall use `QBLP1515A-RGB2A`, both at 1.95 mm pitch; substitutions require written design review. | BOM, placement and incoming-part inspection | Coupon |
| DSP-008 | QBLP1515 LEDs shall keep the manufacturer-recommended pad geometry and use the non-mirrored 0°/90° checkerboard placement defined by ADR 0008. | Footprint audit, generated placement check, PCB DRC, assembly plot and AOI | Coupon |
| MEC-001 | Complete case shall not exceed 110 × 35 × 11 mm, excluding attachment thickness. | Caliper inspection | Final |
| MEC-002 | Complete badge shall aim for ≤75 g and shall never exceed 100 g, including cell, case and magnetic attachment. | Calibrated scale | Final |
| MEC-003 | Development case shall use two M2 screws plus tabs and support a replaceable diffuser. | Fit inspection | Coupon/final prototype |
| MEC-004 | Final design shall tolerate sweat and incidental splashes without claiming an IP rating. | Defined splash demonstration and inspection | Final |
| PWR-001 | A new selected cell shall provide roughly 6 h for the published reference workload and fixed brightness. | Logged full-charge runtime test with external inline battery-current/energy measurement where needed (ADR 0021) | Final |
| PWR-002 | Continuous maximum full-white runtime shall be measured and published separately. | Logged stress runtime test with external inline battery-current/energy measurement (ADR 0021) | Final |
| PWR-003 | OFF-state battery drain with USB absent shall be below 50 µA. | External series ammeter measurement after settling (ADR 0021) | Coupon/final |
| PWR-004 | Switch OFF shall disable the ESP32, display drivers, 3.3 V rail and LED rail. | Rail/current measurement | Coupon/final |
| PWR-005 | With the switch OFF, charging and status shall operate autonomously only from USB-C sources advertising 1.5 A/3 A; all other sources leave the charger in standby. | State-matrix test (ADR 0013) | Coupon/final |
| PWR-006 | Operation while charging shall remain stable; the charger power path shall respect the input limit. | Load/charge test, USB power log and external inline battery-current log (ADR 0021) | Coupon/final |
| PWR-007 | The latching switch shall disconnect the fuel gauge in OFF while preserving hardware-only charging/status. On return to ON, initially uncertain SOC/runtime shall be identified as provisional until validated against the chosen pack. | OFF isolation/current test, OFF-charge state matrix and post-ON SOC comparison (ADR 0015) | Coupon/final |
| PWR-008 | The TPS631000 3.3 V application converter shall maintain at least 4.2 µF effective input and 10.4 µF effective output capacitance over the qualified rail, temperature and lifetime conditions, and hold the ESP32 module pads within 3.0–3.6 V during the defined operating/transient tests. Parallel coupon capacitors are a provisional implementation choice (ADR 0017). | Exact-part derating evidence, full-rail source-state review, layout/ERC/DRC, startup/load-step/attach-detach pad measurements and Gate A review | Coupon/final |
| USB-001 | Use a USB-C receptacle on the right short edge with 5 V input only; USB PD is not required. | Inspection and source test | Coupon/final |
| USB-002 | Enumerate native USB in both connector orientations with compliant A-to-C and C-to-C cables while switched ON. | Enumeration matrix | Coupon/final |
| USB-003 | Hardware shall bound total USB input draw for startup, standby, permitted charging and Type-C source changes; higher Type-C current shall not depend on application firmware. | Complete source-state analysis plus unprogrammed-board, configuration, suspend and attach/detach tests (ADR 0009) | Coupon/final |
| USB-004 | USB-A/default-current Type-C sources shall not charge or supply the application through the charger. Native USB data remains available while ON from battery power; recovery with a depleted/absent battery on these sources is not guaranteed. | USB data and power-state tests (ADR 0013) | Coupon/final |
| USB-005 | Use one fixed external input-current setting, bounded by the existing 0.9753 A ceiling, enabled only by qualified Type-C 1.5 A/3 A hardware permission. No switched ILIM resistor or firmware charge grant. Budget all VBUS loads within source allowance. | Complete-port budget and source-transition tests (ADR 0013) | Coupon/final |
| USB-006 | Account for 5.5 V normal VBUS at light load; derive the low-voltage and transient envelopes separately. Do not use a 5.25 V draft assumption as full input qualification. | Source-envelope and protection review (ADR 0014) | Coupon/final |
| CHG-001 | Prioritize the finished size and roughly six-hour reference runtime over charging speed. With the display off and a qualified USB-C source, document an exact-pack-specific time-to-80% and time-to-full planning target before Gate A and measure both on the coupon/final hardware. Charging shall remain within the terminated pack's current, temperature and protection limits; the previous 45–60/75–100 min targets are withdrawn (ADR 0016). | Exact-pack profile and current-limit review; dated charge log showing pack, source, ambient and hardware revision | Coupon/final |
| CHG-002 | Charge current shall never exceed the exact terminated-pack rating. | BOM/calculation review including qualified total ISET resistance error (ADR 0012), exact-pack rating and external inline pack-current log (ADR 0021) | Coupon/final |
| CHG-003 | A battery-facing NTC connected to the charger and a charger safety timer shall qualify charging without MCU assistance. The NTC may be pack-integrated or board-mounted under ADR 0019; a board-mounted sensor requires measured cell-to-board temperature bounds before final approval. | NTC hot/cold/open/short tests; simultaneous cell-surface and board-sensor logs for a board-mounted NTC | Coupon/final |
| RF-001 | BLE shall be disabled during normal playback. | Firmware state and current test | Coupon/final |
| RF-002 | Holding the mode button for approximately three seconds shall enter programming mode and enable BLE. | Functional test | Coupon/final |
| RF-003 | Programming-mode BLE shall work at 3 m line-of-sight in normal worn orientation. | Range test | Coupon/final |
| CTL-001 | Provide one momentary mode button and one real latching slide switch on the top edge. | Inspection and functional test | Coupon/final |
| STO-001 | Store at least 24 representative assets totalling five minutes alongside two application slots. | Image/partition and playback test | Coupon/final |
| MFG-001 | Maintain vendor-neutral KiCad, Gerber, drill, BOM and placement sources. | Release inspection | Coupon/final |
| MFG-002 | PCBA delivery shall require no manual SMT soldering by the user. | Purchase package and incoming inspection | Coupon/final |
| MFG-003 | Critical component substitutions require a written engineering review and updated BOM. | Release audit | Coupon/final |
| SAF-001 | Use a protected, documented and keyed connectorized LiPo pack. A two-wire pack is permitted when the charger has the independently operating battery-facing NTC arrangement and validation in ADR 0019. | Supplier documentation, connector/polarity inspection and temperature-sensing qualification | Coupon/final |
| SAF-002 | No cell surface may contact a component, solder joint, magnet or screw boss; swelling clearance is required. | CAD interference and physical inspection | Final |
| SAF-003 | An experienced hardware engineer shall review the coupon schematic and preliminary layout before fabrication. | Recorded review disposition | Coupon |
| SRC-001 | Quote JLCPCB, PCBWay and a vetted Alibaba turnkey PCBA supplier against the same frozen package. | Quote comparison | Final |
| CST-001 | Target USD 500–800 for coupon, five final PCBAs, cells, basic test tools and shipping, excluding independent review and case filament/design. | Quote ledger | Project |

## Reference workload

The provisional runtime workload consists of representative text, icons and animations with approximately 35% of pixels lit and brightness fixed at 25% of the validated hardware maximum. It is a repeatable engineering benchmark, not a restriction on user content. Coupon measurements will define the final asset bundle and calibrated power model.

## Power-architecture proposal verification addendum

2026-10-05: [ADR 0018](decisions/0018-complete-power-architecture-proposal.md) is **proposed, not an accepted replacement of the table above**. These verification refinements must be adopted/resolved before its material circuit changes are implemented. No current ceiling, battery rating or fabrication gate is relaxed.

| Existing requirements | Proposed refinement / acceptance evidence |
|---|---|
| USB-003/004/005/006, PWR-005 | Treat an independently disconnected charger input as the proposed physical implementation of unsupported-source standby; preserve battery-only application operation. Prove default-disable and total port current through startup, all partial-supply states, source downgrade and detach, including capacitance outside the charger limiter. |
| PWR-003/004/007 | Verify arbitrary switch-contact order, settling and bus isolation with either gauge or application rail absent/decaying; no reliance on firmware to order physical contacts. Retain provisional SOC after ON. |
| PWR-001/002 | Include added buffer/control losses and exact-pack minimum capacity/cutoff in the model before battery freeze; preserve fixed-brightness workload and separate full-white result. |
| DSP-006, PWR-004/008 | Hardware must keep VLED disabled and rows blank at boot, all reset paths, programming entry and physical OFF; audit residual rail energy, programmer injection and watchdog behavior. Define the exact interlock before capture. |
| CHG-001/002/003, SAF-001/002 | Select ISET, charge voltage, ITERM, NTC network and timer from the exact pack and full thermal budget; the 2.49 kΩ / 396 mA maximum is a conditional numerical proposal, not an approved BOM population. |

The [proposal's six capture holds](design/power-architecture-2026-10-05.md#8-one-consolidated-capture-hold-list) separate required engineering evidence from the remaining supplier information. Native ERC alone does not close them.

**2026-10-07 USB-005/PWR-006/CHG-001 proposal:** [ADR 0022](decisions/0022-lower-fixed-usb-input-limit-proposal.md) screens one fixed 3.65 kΩ ILIM resistor, calculated at 0.361–0.476 A, to separate the charger's steady input limit from the screened eFuse breaker threshold. It is not accepted or captured. Before adoption, verify charge-through operation and pack-specific charge times at the lower input limit, as well as the complete USB load/startup/fault envelope. Existing current ceilings and safeguards remain in force.

**2026-10-07 PWR-005/USB-003/005 proposal:** [ADR 0023](decisions/0023-charger-en2-local-clamp-proposal.md) screens an EN2 mode source from the admitted charger input with a 2.5 V local clamp. Before adoption, audit the shunt symbol/pads, confirm EN2 current across the intended clamp voltage, verify the resistor's local thermal rating, and capture attach/detach/downgrade/trip waveforms. This does not approve the charger gate or fixed-mode timing.

**2026-10-09 CHG-001/002/003, SAF-001/002 design target:** [ADR 0024](decisions/0024-lp452845-pack-and-temperature-window.md) selects the protected `LP452845`/PHR-2 assembly of drawing FD_6225_10 index 1 and mating JST `S2B-PH-SM4-TB` for Rev A design. Keep its +10…+45 °C charge range, 450 mA charge ceiling and 4.20 V ±50 mV charge-voltage limit in the part-specific acceptance case. The BQ24074 TS NTC and safety timer remain active; an additional TMP390 hot/cold switch with a 10 kΩ output pull-up and AUP gate inhibits E1 at nominal 40/15 °C board temperatures. Prove combined sensor tolerance and cell-to-board thermal error leave the cell inside its charge range, test open/short and startup/fault states, and verify exact assembly polarity, discharge duty and current limits before BOM freeze. A source-design target is not a tested pack or fabrication approval.

**2026-10-10 CHG-002 capture part:** ADR 0024 selects exact Panasonic `ERA2AEB2491X` (2.49 kΩ, 0.1%, ±25 ppm/K) as the ISET source part, now placed in the provisional charger core. Preserve the ±1% total resistance allowance and calculated 396 mA maximum; source capture does not approve charge-current, pack thermal or a fabrication BOM.

**2026-10-10 CHG-001/002/003 and USB-005 provisional capture:** The root-linked charger core connects BQ24074 `TS` to the battery-facing Murata NTC, exact `ERA2AEB2491X` at ISET and one exact `ERA2AEB3651X` at ILIM. ADR 0022 now selects the single lower ILIM setting for provisional capture, retaining the calculated 0.361–0.476 A interval when external mode is later enabled. The currently grounded EN2/EN1 pins keep the disconnected core in the 100 mA fallback mode; ILIM does not set that fallback limit. `ITERM` remains open for internal 10% termination and `TMR` open for TI's active default precharge/fast-charge safety timers, nominal 30 minutes/5 hours. The disconnected IN and BAT nets carry explicitly provisional ERC source flags pending E1 and exact pack connector; they are not physical supplies. Before gate/pack capture, review capacitor effective values and voltage stress, full-port and pack current, charging time versus timer, polarity, temperature tolerance and thermal behavior. Native ERC and XML connectivity do not satisfy these operating acceptance checks.

## Row-package proposal verification addendum

2026-10-06: [ADR 0020](decisions/0020-dual-row-mosfet-package-proposal.md) proposes a complementary N/P package for each row to recover board area. It is **not accepted or implemented**. The following evidence is required before it could replace the captured row stage; the display, current and fail-safe requirements above remain unchanged.

| Existing requirements | Proposed refinement / acceptance evidence |
|---|---|
| DSP-001/004/006, PWR-004 | Preserve 16 independently selected rows and hardware-default blanking during boot, reset, programming, OFF and VLED faults. Verify turn-off and row dead time under real multiplex timing, including visible ghosting. |
| PWR-006/008, USB-003, CHG-002 | Bound a final 48-pixel row's current, tolerance and overlap/fault cases at the selected VLED rail. Review the candidate P device's hot resistance, switching loss, SOA, gate stress and compact-board copper; the manufacturer's large test-board current rating is not a badge rating. Do not raise existing limits through a package change. |
| MFG-001/003, SAF-003 | Audit the exact manufacturer's N/P pin map, land pattern, polarity/pin-one mark and assemblability into project-local libraries. If selected, use the same stage on the coupon and measure it before relying on coupon results for the final board; include it in the independent Gate A review. |

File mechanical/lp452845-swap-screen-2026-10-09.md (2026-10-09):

<!-- SPDX-License-Identifier: CERN-OHL-S-2.0 -->

# LP452845 connectorized-pack swap screen

The [LiPol finished-assembly drawing FD_6225_10, index 1](https://www.lipobattery.us/wp-content/uploads/2022/08/LP452845-3.7V-900mAh-with-JST-PHR-2.pdf) specifies a protected `LP452845` with two AWG 26 leads and JST `PHR-2`, no integrated NTC. Its maximum drawn body is **47 × 28.5 × 4.8 mm**, compared with **56 × 30.5 × 5.3 mm** for the protected, bare-wire `LP503055`. This corrects the earlier sourcing note that no finished drawing was available. The [model page](https://www.lipobattery.us/900mah-lipo-battery-lp452845-3-7v-900mah-3-33wh-with-protection-circuit-and-wires-50mm-and-jst-phr-2/) says five-piece samples may ship in a week **when stocked**; it does not establish live stock, price or a purchase-ready order.

The [reproducible geometric comparison](review/lp452845-swap.json) shifts the new maximum body **1.5 mm right of centre** on the same 106 × 32.5 mm board and reuses the existing October 6 anchor rectangles. It is a swap screen, not a new packed PCB:

| Result | Existing LP503055 | LP452845 swap |
|---|---:|---:|
| Maximum body projection | 56 × 30.5 mm | 47 × 28.5 mm |
| Maximum body thickness | 5.3 mm | 4.8 mm |
| Outside-body board area recovered | — | 368.5 mm² |
| Illustrative case-section total with 0402 beneath pack | 10.75 mm | 10.25 mm |
| Nominal unused height in 11 mm case | 0.25 mm | 0.75 mm |
| Existing 77 under-pack 0402 XY positions still inside the body | 77 | 34; **43 need moving** |
| Free 8 × 9.6 or 9.6 × 8 mm PH pocket positions with old anchors | 0 | 0 |

The shorter body improves nominal height and area, but it does not make the **original grouped placement** fit a PH connector. The earlier 9.6 × 8 mm rectangle was also too shallow: [JST's side-entry SMT board layout](https://www.jst-mfg.com/product/pdf/eng/ePH.pdf) calls for **9 mm minimum depth**. In the separate, still-proposed [dual-row-package variant](dual-row-package-screen-2026-10-06.md), the KiCad 10.0.6 `S2B-PH-SM4-TB` footprint has a **9.2 × 10.2 mm courtyard**, placed at x=20.25–29.45, y=0.25–10.45 mm. The shifted pack begins at x=31.0 mm, leaving **1.55 mm XY** between body and connector courtyard. Captured 0805 output capacitor `C42` moves to x=16.5–20.25, y=0.25–2.25 mm. Moving 43 of the 77 conditional under-pack 0402 boxes gives all 77 nonoverlapping XY positions inside the shifted pack projection while retaining 34 old positions and moving the battery-facing sensor reservation with the pack. The exact positions are in the [JSON](review/lp452845-swap.json). This shows one possible *geometric* repack; it does not approve the dual-row electrical substitution or establish a routed board.

The revised screen reserves a **10 × 8 mm battery-facing sensor cluster** at x=49.5–59.5, y=12.25–20.25 mm. Eight nonoverlapping trial boxes represent the Murata BQ TS NTC, `TMP390A2DRLR`, its two threshold resistors and 10 kΩ output pull-up, two exact Murata bypass capacitors, and the second AUP inhibit gate. All 77 earlier under-pack 0402 courtyards still fit outside that cluster in this XY screen. The TMP390's 2.7 × 2.5 mm box now matches its [project-local first-author DRL0006A courtyard](../hardware/coupon/rev-a/tmp390-library-audit.md); the screen does not establish routability, sensor thermal coupling, or space for mounting adhesive and insulation.

The connector footprint courtyard is a more useful anchor than the old illustrative pocket, but its solder lands and pin-one mark still require independent comparison with JST's mounting-side drawing before board capture. The mated housing, lead bend, strain relief, insulating support, swelling tolerance, heat, C42 electrical locality and copper/routing are still absent. The actual connector polarity must be checked on the terminated assembly. No physical pack, board or case has been measured.

Electrically, the drawing gives **900 mAh minimum**, **450 mA maximum charge**, **900 mA maximum discharge** and a **+10 to +45 °C charge range**. [ADR 0024](../docs/decisions/0024-lp452845-pack-and-temperature-window.md) now selects this exact terminated assembly as the Rev A **design target**. The proposed 2.49 kΩ ISET upper calculation of 396 mA is 54 mA below the listed charge ceiling, conditional on total resistor error and pack qualification. The reference model gives 0.9 Ah × 3.7 V × 85% / 0.45 W = **6.29 h idealized**; this is only 0.29 h above the six-hour target before measured variation. The existing 2.49 W full-white model gives 0.83 A at 3.0 V, only 0.07 A below the pack's *maximum* discharge statement, which is **not explicitly a continuous rating**. The chosen battery-facing NTC and additional hardware hot/cold guard must be tested against cell-surface temperature before the pack, charger and layout can be frozen.

Source data and calculations are recorded in [the dated sourcing update](../docs/sourcing/pack-screen-2026-10-05.md). The geometric script reads the saved [October 6 fit trial](review/fit-trial.json); it does not rerun the native KiCad inventory or optimize electrical locality.

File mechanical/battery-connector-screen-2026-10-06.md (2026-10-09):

<!-- SPDX-License-Identifier: CERN-OHL-S-2.0 -->

# Battery connector and board-space screen

Status: **candidate and geometry screen, not a connector or pack selection**. The leading LiPol `LP503055` drawing specifies a protected, bare-wire pack with two AWG 28 leads, a 475 mA maximum charge current and a 950 mA maximum continuous discharge current. The wire insulation diameter, exact cable exit after termination, stocked assembly, connector polarity and crimp quality are not documented for a connectorized order. The pack remains unselected. [LiPol drawing](https://www.lipolbattery.com/LiPo-Battery-Datahseet/LiPo_Battery_LP503055_3.7V_950mAh.pdf).

## Candidate comparison

| Family | Manufacturer evidence | Disposition |
|---|---|---|
| JST GH, 1.25 mm pitch, locking `SM02B-GHS-TB` + `GHR-02V-S` + `SSHL-002T-P0.2` | 1.0 A rating **at AWG 26**; contact accepts AWG 30–26 and 0.76–1.0 mm insulation. [JST GH specification](https://www.jst-mfg.com/product/pdf/eng/eGH.pdf). | Compact, but its published 1.0 A test wire is not the pack's AWG 28. No #28 current margin has been established against the pack's 0.95 A continuous capability. Do not freeze it from the family rating alone. |
| JST PH, 2.0 mm pitch, side-entry SMT `S2B-PH-SM4-TB` + `PHR-2` + `SPH-002T-P0.5S` | 2 A family rating **at AWG 24**; the named crimp contact accepts AWG 30–24 with 0.8–1.5 mm insulation. The SMT side-entry header is listed by JST. [JST PH specification](https://www.jst-mfg.com/product/pdf/eng/ePH.pdf). | Better provisional electrical margin and compatible wire gauge range, subject to the actual AWG 28/insulation-specific current rating, mating orientation, polarity and supplier termination. Its mated package is substantially harder to fit. |
| Molex PicoBlade, 1.25 mm pitch, right-angle SMT `53261-0271` + `51021-0200` + `50079-8000` | Molex lists this two-circuit header/housing family, AWG 26–28 crimp contact and **2.0 A reference current at AWG 28** for the two-circuit wire-to-board configuration. The rating is reference data based on a 30 °C crimp-barrel rise, and board traces affect it. [Molex PicoBlade specification](https://www.content.molex.com/dxresources/e24c/e24ca95a-11dc-46d6-be7b-592110a37b66.pdf), [header drawing](https://www.molex.com/content/dam/molex/molex-dot-com/products/automated/en-us/salesdrawingpdf/532/53261/532610471_sd.pdf). | **Preferred geometry-trial candidate:** more directly documented AWG 28 current headroom than GH/PH in the sources reviewed, smaller pitch, but friction retention rather than a positive lock. Exact insulation diameter, crimp, polarity, cable routing and sourcing remain open. |

The connector must be ordered as an **exact matched assembly**, with pin 1/pin 2 polarity checked from the header mounting-side view through the mated housing to red/black pack wires. Neither this screen nor the common connector-family name establishes that polarity. The battery supplier or qualified cable assembler must confirm the crimp terminal, insulation diameter, pull test and protected pack assembly. No substitution of a generic “JST battery connector” is permitted.

## Existing rear-layout screen

The [fit-trial generator](../tools/screen-final-fit-trial.py) now tests a deliberately illustrative **8.0 × 9.6 mm** side-entry, mated-connector pocket in both orientations on a 0.25 mm grid. It excludes the battery body and currently anchored courtyards. The [machine-readable result](review/fit-trial.json) finds **zero free pocket positions in either orientation even before the remaining small parts are first-fit** on the current 106 × 32.5 mm trial board. This is a conditional collision result for that particular grouped arrangement, not a conclusion that a reworked KiCad placement cannot fit a connector. The pocket is not a transcribed JST land pattern; wire bend, strain relief, case wall, routing and mounting features would require more space.

The useful next placement change is to move the USB/driver/row-stage groups as a whole while reserving the connector and wire exit first, then pack the remaining small parts. Do this with an exact pack termination and a manufacturer-audited project-local connector footprint. The complete power netlist and case support are still absent, so this screen does not authorize a PCB or pack order.

The follow-on [connector-first arrangement](connector-first-trial-2026-10-06.md) uses an illustrative 8 × 8 mm pocket for the Molex candidate, moves the top-edge switch and row decoder, and repacks the row FETs. It is still incomplete and does not replace either manufacturer's land drawing.

**2026-10-09 design update:** [ADR 0024](../docs/decisions/0024-lp452845-pack-and-temperature-window.md) selects the exact LP452845/PHR-2 assembly and JST `S2B-PH-SM4-TB` header as the Rev A design target. The first 9.6 × 8 mm PH rectangle proved too shallow when checked against [JST's side-entry SMT layout](https://www.jst-mfg.com/product/pdf/eng/ePH.pdf), which calls for 9 mm minimum board depth. The [corrected LP452845 swap screen](lp452845-swap-screen-2026-10-09.md) instead uses KiCad 10.0.6's 9.2 × 10.2 mm S2B-PH-SM4-TB courtyard, shifts the pack 1.5 mm right and relocates one nearby 0805 capacitor. It still has no verified mated-cable bend, current derating for the exact AWG 26 termination, or measured pack polarity. The earlier Molex comparison remains historical and is not the selected header.

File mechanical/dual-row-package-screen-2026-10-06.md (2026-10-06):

<!-- SPDX-License-Identifier: CERN-OHL-S-2.0 -->

# Conditional dual-row package XY screen

The [to-scale rear plan](review/dual-row-package-plan.svg), [magnified converter bay](review/vled-cluster-detail.svg) and [machine-readable positions](review/fit-trial.json) test the geometry consequence of [proposed ADR 0020](../docs/decisions/0020-dual-row-mosfet-package-proposal.md). Regenerate them with `python3 tools/screen-final-fit-trial.py`. This is an **unrouted package-area screen**, not a new schematic, footprint, selected battery termination or qualified PCB fit.

The starting point is the [connector-first trial](connector-first-trial-2026-10-06.md): 106 × 32.5 mm board, centred 56 × 30.5 mm LP503055 projected body, illustrative 8 × 8 mm Molex connector pocket, relocated switch and decoder, three projected driver bodies and 77 conditional 0402 positions below a separately supported pack. This screen removes only the **32 original row MOSFET courtyards** from that trial and reserves sixteen **3 × 3 mm candidate courtyards** for `DMC1229UFDB-7` complementary N/P pairs, read from the [first-author project footprint](../hardware/coupon/rev-a/dual-row-package-library-audit.md). It retains every other captured coupon part. A tighter trial moves decoder `U2` to the upper-right edge, freeing the lower-right strip for the thirteen parts of the [unlinked VLED converter](../hardware/coupon/rev-a/vled-converter-capture-contract.md). It also reserves one BQ24074 and two TPS259474 IC courtyards. [ADR 0021](../docs/decisions/0021-external-battery-current-measurement.md) removes the originally planned INA232 monitor/shunt; its IC box is included only in a historical comparison. These IC-package minima are **not complete power circuits**.

| XY screening result | Count or area |
|---|---:|
| Original separate row MOSFET courtyards | 32; 397.6 mm² |
| Hypothetical dual-package allowances | 16; 144.0 mm² |
| Nominal row-stage courtyard area recovered | 253.6 mm² |
| Retained captured non-row parts without an XY position | 0 |
| Proposed power-IC package minima without an XY position | 0 of 4 included |
| Unlinked VLED candidate passive courtyards without an XY position | 0 of 12 |
| Conditional under-pack 0402 trial positions | 77 |
| Historical INA232 included with the same first-fit order | 15 of 16 pair boxes placed; captured non-row parts still all placed |

The VLED cluster occupies an 11 × 9.3 mm envelope at x=91–102 mm, y=22.8–32.1 mm. Its IC courtyard is x=91–95.9 mm, y=25.5–29.4 mm. The rotated inductor is directly to the right, bridging the IC's switching-pin sides; first input capacitor `C44` and first output capacitor `C46` are on their respective pin sides, each 2.974 mm centre-to-centre from the IC. The farthest extra output capacitor is 7.558 mm from the IC centre. The divider's grounded end was moved into the resistor box nearest U37; native pad inspection gives 3.042 mm from R86's ground pad to U37's control-ground pad. These are XY distances, **not routed loop lengths or pad-to-pad clearances**. A [separate native KiCad placement](../hardware/coupon/rev-a/staging/vled-layout-trial.kicad_pcb) instantiates the thirteen actual project footprints and exports the staged schematic nets to their pads. It has no neighbouring final-board circuitry, tracks, vias or zones. A [desktop-access local-board DRC](../docs/development/vled-layout-trial-2026-10-06.md) found zero geometry violations and thirty expected unconnected items; a [separate partial routing study](../docs/development/vled-routing-trial-2026-10-06.md) leaves twenty open. [TI's layout guidance](https://www.ti.com/lit/ds/symlink/tps63020.pdf) calls for short, wide power paths, nearby input/output capacitors and inductor, a quiet control-ground/feedback path, and separated power/control ground regions. This trial has not met those instructions yet.

All drawn XY boxes are nonoverlapping, sometimes with **zero added gap**. The decoder move remains a layout variant; ADR 0021 separately accepted the monitor omission after retaining external measurement evidence. The INA232 comparison proves only that this first-fit order loses one pair box when its IC courtyard is restored; a better whole-board placement might fit it. The candidate pair land geometry was transcribed from the manufacturer Type B package file, but its pin numbering, paste/mask, mounting and actual routing have not passed independent review. The proposal still omits charger/input-support passives and inductors, gauge buffering, hardware display interlock, two extra driver support networks, USB/RF and battery cable routes, thermal copper, assembly access and full 11 mm section tolerances. The LP503055 is still an unselected terminated-pack candidate; its cell/body drawing does not settle protection, connector polarity or wire bend. None of those omissions can be inferred to fit from this drawing.

**Disposition:** the tighter VLED grouping is a useful starting location for a real PCB placement, but the full circuit cannot yet be credited as fitted. ADR 0021 removes live signed current telemetry while preserving external coupon/final current logs. Independently check the candidate row-package pin/land geometry and bound final-row current and compact-board heat, then decide whether the coupon should carry the new row stage. Continue the complete coupon power circuit and exact-pack search in parallel. The manufacturer's [dual MOSFET datasheet](https://www.diodes.com/datasheet/download/DMC1229UFDB.pdf) supplies package and electrical screening values; the 3 × 3 mm courtyard is a project placement allowance.

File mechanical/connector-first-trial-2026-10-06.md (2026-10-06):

<!-- SPDX-License-Identifier: CERN-OHL-S-2.0 -->

# Connector-first rear layout trial

The [to-scale rear plan](review/connector-first-plan.svg) and [position record](review/fit-trial.json) come from the native coupon KiCad netlist and project-local captured footprint courtyards. Regenerate them with `python3 tools/screen-final-fit-trial.py`. This is an **unrouted geometric trial**, not a PCB, a qualified battery installation or a complete final-badge circuit.

The trial reserves an **illustrative 8 × 8 mm pocket** next to the left end of a centred, separately supported LP503055 pack. The pocket represents a candidate two-circuit Molex PicoBlade right-angle connector and an initial mated-area allowance; it is **not** a transcribed land pattern, full wire bend or strain-relief envelope. The switch remains on the top edge but moves to the right. The row decoder moves below the USB connector. The MCU, three driver bodies, USB connector, battery body and 77 conditional under-pack 0402 positions keep their previous trial envelopes. The 32 row FETs are then repacked bottom-up, followed by the remaining captured parts with zero extra gap beyond their courtyards.

| Geometry result | Count |
|---|---:|
| Row FETs given nonoverlapping XY positions | 28 of 32 |
| Other captured coupon parts given first-fit XY positions | 32 |
| Captured coupon parts still unplaced | 11: `Q1`–`Q4`, `U11`, `U17`, `U23`–`U25`, `U29`, `U34` |
| Conditional 0402 XY positions under the pack | 77 |

All drawn trial rectangles are nonoverlapping, but several share courtyard edges and have **no added routing or assembly gap**. Pin orientation, signal paths, decoder-to-row distance, converter locality, RF, heat and copper area have not been checked. This alternative therefore does not solve the placement problem: it trades the earlier eight unplaced captured parts for eleven after reserving a connector pocket. Charger, LED converter, input protection, connector land pattern, their support passives, mounting and cable path remain absent.

A useful area check reinforces the concern without proving an impossible layout. The 106 × 32.5 mm board has 1,737 mm² outside the LP503055's centred 56 × 30.5 mm projected body. At the time of this screen, the drawn and still-unplaced captured courtyards, the 64 mm² illustrative connector pocket, and five proposed power-IC package minima left roughly **120 mm²** of nominal outside-pack area. [ADR 0021](../docs/decisions/0021-external-battery-current-measurement.md) subsequently removed the on-board INA232/shunt; the [later cluster screen](dual-row-package-screen-2026-10-06.md) uses four power-IC allowances. That remainder must also accommodate power passives/inductors, interlock and gauge support, mounting, isolation, copper and routing; this older screen does not allocate them. Some passives may sit beneath the pack only if the separate vertical, thermal and locality qualification succeeds.

**Disposition:** keep the 106 × 32.5 mm board and 110 × 35 × 11 mm case as trial targets for now. A full-board PCB is premature because the complete power netlist, exact terminated pack and audited connector footprint are unavailable. The largest currently captured outside-pack area is the 32-device row-switch bank (about 398 mm² of courtyards). Any attempt to reduce it is a material electrical change requiring a reviewed current/thermal/default-off circuit and ADR before capture. In parallel, a shorter protected pack could free board area, but it must still meet the full-white current and runtime requirements; the existing 900 mAh LP452845 listing is not a qualified replacement. The first physical milestone remains the 16 × 16 coupon and its independently reviewed power design.

A [follow-on package screen](dual-row-package-screen-2026-10-06.md) tests the most promising row-stage area reduction under a proposed ADR. It does not change this connector-first result or implement a new circuit.

Manufacturer sources: [LP503055 protected-pack drawing](https://www.lipolbattery.com/LiPo-Battery-Datahseet/LiPo_Battery_LP503055_3.7V_950mAh.pdf), [Molex PicoBlade connector data](https://www.content.molex.com/dxresources/e24c/e24ca95a-11dc-46d6-be7b-592110a37b66.pdf), [Molex right-angle header drawing](https://www.molex.com/content/dam/molex/molex-dot-com/products/automated/en-us/salesdrawingpdf/532/53261/532610471_sd.pdf).

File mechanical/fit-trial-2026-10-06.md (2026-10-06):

<!-- SPDX-License-Identifier: CERN-OHL-S-2.0 -->

# Final-badge board and battery fit trial

The [rear plan](review/fit-trial-plan.svg), [front LED/USB screen](review/placement.svg), [11 mm section](review/fit-trial-section.svg) and [machine-readable positions](review/fit-trial.json) are an early, to-scale fit trial. Rebuild the rear and section artifacts from the current native KiCad coupon netlist and project-local footprint courtyards with:

```sh
python3 tools/screen-final-fit-trial.py
```

This is **not a KiCad PCB**, routing/DRC, complete 48 × 16 netlist, approved battery mount or case CAD. It is a deliberate test of the current 106 × 32.5 mm board and 110 × 35 × 11 mm case targets before changing requirements. The [LP503055 manufacturer drawing](https://www.lipolbattery.com/LiPo-Battery-Datahseet/LiPo_Battery_LP503055_3.7V_950mAh.pdf) gives a maximum finished body of 56 × 30.5 × 5.3 mm for its bare-wire configuration. It is a separate, wired pack that **must be supported by the enclosure above the PCB**; neither that support, a keyed connector, nor the final local shape of the protection board, wire bend and strain relief is available.

## Plan result

The trial places the ESP32 module at X 0.5–20.1 mm, Y 9.25–29.75 mm, shifts the previously screened three TLC59581 bodies to the right, and puts the existing row decoder, switch/button footprints and all 32 row-MOSFET courtyards into side/top strips. It gives 77 currently captured 0402 resistors/capacitors nonoverlapping **XY candidate positions beneath the pack**, including the row-gate resistor pairs near its driver-side edge. The 4 × 4 mm centre box remains a *target reservation* for the future battery NTC, not its selected land pattern. Courtyards of these anchored parts do not intersect in this projection.

The rest of the captured coupon parts are then tried in the remaining rear rectangles with zero *additional* gap beyond their project-local courtyards. **Eight currently captured parts remain without a position:** U11, U17, U23, U24, U25, U29, U34 and U33 (USB conditioning/permission, logic supply and supervisor). Other automatically assigned parts are only geometric trial positions; their nets, decoupler locality, thermal grouping and routability are unreviewed. The exact top-edge actuator directions for the provisional SW1/SW2 footprints also remain open.

Even this optimistic plan omits major required or proposed final hardware. At the time of this initial screen, the project-local courtyards of the proposed BQ24074 charger IC, TPS63020 LED-supply IC, two TPS259474 input switches and INA232 monitor totalled **64.90 mm²** before their passives, inductors, thermal copper or connections. [ADR 0021](../docs/decisions/0021-external-battery-current-measurement.md) subsequently removed the on-board monitor/shunt from capture; the [later tight-cluster screen](dual-row-package-screen-2026-10-06.md) compares both cases. The keyed pack connector, cable path, gauge isolation, display interlock, two added driver support networks, antenna/cable zone and two M2 mounting features have no assigned location. These are unplaced needs or candidate allowances, not permission to crowd the existing parts or omit required functions.

The [battery-connector screen](battery-connector-screen-2026-10-06.md) evaluates a provisional JST PH side-entry assembly. An illustrative 8.0 × 9.6 mm mated pocket has zero collision-free positions in either orientation **even before** automatic placement of the remaining captured parts. Its actual land pattern, cable direction and wire clearance are not selected. This calls for rearranging the grouped components with a connector reserved first; it does not prove the board outline impossible.

The [connector-first follow-on](connector-first-trial-2026-10-06.md) compares a more compact Molex PicoBlade candidate and deliberately rearranges the control, decoder and row switches around an 8 × 8 mm illustrative pocket. The pocket fits in XY, but 11 captured parts remain unplaced and the power hardware remains absent. The drawing is a specific failed complete-fit trial, not a released connector placement.

## Section result

The [existing envelope trial](envelope-screen-2026-09-26.md) allocates 4.9 mm outside the pack: 0.6 diffuser, 0.5 optical gap, 1.2 front LED height, 0.8 PCB, 0.3 electrical isolation, 0.5 swelling/installation allowance and 1.0 rear shell. Adding the LP503055's 5.3 mm maximum body gives **10.2 mm** before a rear PCB component. For an illustrative **0.55 mm** 0402 MLCC height—shown for the project's GRM155 part in a [Murata manufacturer BOM](https://www.murata.com/-/media/webrenewal/products/connectivitymodule/asset/pub/rfm/data/type2nr/type2nr-evk-bom.ashx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)—the sum is **10.75 mm**, leaving only **0.25 mm nominal** in an 11 mm case.

That 0.25 mm is **not qualified clearance**. Assembled heights, solder, film or rigid cover, adhesive, supports, cell swelling, wall/diffuser tolerances and the thermal delay/error of the board NTC are not bounded by this arithmetic. There is no approved mount that guarantees the pack never presses on a component or solder joint. The 77 under-pack XY positions therefore remain conditional and cannot be transferred blindly to a PCB.

## Disposition

The current outline **does not yet pass a complete fit trial**: eight existing parts and all remaining power/connector/RF/mounting needs are unplaced, while the under-pack section has little nominal height margin. This does not prove that a skilled layout or revised case stack cannot fit. It does show that the earlier generic first-fit count was not the right decision metric, and that no reduction in display resolution or safety clearance is justified from it.

The next electrical input needed for a release-grade layout is a complete power netlist and exact connector/antenna choices. In parallel, the enclosure trial should specify a real insulating battery support and measure the full height/tolerance stack with inert pack mockups. Then a KiCad PCB can place the complete netlist, run DRC, and go through independent Gate A review. No board or pack has been physically fitted or ordered.

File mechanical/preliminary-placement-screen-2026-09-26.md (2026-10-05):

<!-- SPDX-License-Identifier: CERN-OHL-S-2.0 -->

# Preliminary front/rear placement screen

2026-09-26. [Review drawing](review/placement.svg) and [machine-readable result](review/placement.json). Generate both from the canonical, project-local footprints with:

```sh
python3 tools/screen-preliminary-placement.py --output mechanical/review
```

This is a **two-dimensional bounding-box calculation**, not a KiCad PCB, completed component placement, DRC, manufacturer-approved board outline or cell fit. It screens the hypothetical **final 48 × 16 board**, not the 16 × 16 mixed-LED coupon. Preliminary dimensions are 106 × 32.5 mm, with a 1.95 mm pitch. To see spatial feasibility independently of coupon power choices, the drawing uses 48 columns of the QT Brightek QBLP1515A-RGB2A candidate; Gate B has not selected the final LED. All LED courtyards follow [ADR 0008](../docs/decisions/0008-qblp1515-checkerboard-placement.md). The USB4505 footprint's drawing guides determine the connector's position. Its corner reliefs are not dimensioned; the opening in the drawing is a straight-sided **guide only**.

## Results

| Check | Calculated outcome | Practical reading |
|---|---:|---|
| Centred final grid against USB4505 F.CrtYd | **8 LED courtyard overlaps**; worst horizontal intrusion 1.525 mm | The previous 0.025 mm copper/cutout overlap is only part of the placement problem. Courtyard is an assembly reservation, not necessarily a solid shell outline. |
| Trial array shift left 1.775 mm | Zero LED/USB **courtyard box** overlaps; nearest horizontal gap 0.25 mm | Illustrative layout adjustment only; this does not establish a safe LED-to-shell gap, body clearance or manufacturing rule. |
| Trial leftmost LED courtyard | X = 4.3 mm on a 106 mm board | The grid remains inside this draft board rectangle; actual optical registration and wall alignment are unverified. |
| Rear large-component rectangles | Module at (14.5, 16.25) mm; three TLC59581 footprint centres at X = **86.5 mm**, Y = 5.0/16.25/27.5 mm; 700 mAh coupon pack **50.5 × 31.0 mm** centred (drawing's 30.5 mm width plus 0.5 mm) | The selected bounding rectangles stay on the board and do not overlap one another in XY. The coupon-pack-to-driver courtyard gap is **3.80 mm**, without routing, a connector, swelling, insulation, standoffs or height checks. |

## Battery-facing NTC trial location, 2026-10-05

Under [ADR 0019](../docs/decisions/0019-board-mounted-battery-temperature-sensing.md), mark the **centre of the shared rear battery area, X = 53.0 mm, Y = 16.25 mm**, as the first board-NTC XY target. The red dot in the drawing records that target, not a selected NTC footprint or an electrically connected sensor. It is centred under both the original coupon-only pack rectangle and the provisional `LP503055` body outline. Reserve electrical insulation and mechanical clearance between the pouch and the populated board; the sensor must not press into the cell or consume its swelling allowance. The actual footprint and final XY can move when the PCB, enclosure and pack assembly are laid out.

The orange `LP503055` outline uses its [manufacturer finished-body drawing](https://www.lipolbattery.com/LiPo-Battery-Datahseet/LiPo_Battery_LP503055_3.7V_950mAh.pdf) maxima of **56 × 30.5 mm**, centred on this trial board. The first trial at driver X = 83.0 mm overlapped all three driver courtyards by 2.45 mm. Moving their centres to **X = 86.5 mm** leaves **1.05 mm** between the finished pack body and their courtyards, while the middle driver ends **7.45 mm** before the USB connector courtyard. These are 2D box gaps, not required battery clearance or room for all remaining circuitry. The lead exit, protection-board protrusion, connector, swelling allowance and routing are still absent. Temperature thresholds remain conditional on the exact pack and coupon cell-to-board measurements.

The manufacturer drawing's straight USB opening reaches 6.20 mm into the right edge; the project USB footprint's front courtyard reaches **7.60 mm inward**. Moving only 0.275 mm left to create nominal 0.25 mm pad-to-*cutout* clearance, as calculated in the [earlier edge screen](usb-led-edge-screen-2026-09-26.md), still intersects the USB courtyard. This updated screen protects against solving the wrong clearance.

The rear battery rectangle is the **protected GlobTek BL0750F5030481S1PCTC 700 mAh coupon-only candidate** from the [pack screen](../docs/sourcing/pack-screen-2026-09-25.md). [GlobTek Rev D page 4](https://www.globtek.com/pdf/manual-datasheets/BL0750F5030481S1PCTC.pdf) specifies 50.5 × 30.5 (+0.5) × 5.3 (+0.3) mm: this rectangle includes the documented **maximum width** of 31.0 mm, but wire exit/connector position, pouch swelling, mounting and insulating clearance remain outside it. It is **not an approved final battery**: the full-badge reference runtime model is about 4.9 h and the estimated maximum-white draw exceeds its documented continuous-discharge rating. An actual final pack may have very different dimensions.

The rear boxes represent only the MCU, three LED drivers and nominal pouch, **not** the decoder, sixteen row switches, charger, protection, converters, magnet/screw zones, antenna and feedline, USB shell, test pads or all of their routing. The 1.05 mm LP503055-to-driver gap does not establish electrical insulation, pouch expansion or assembly access. The actual 11 mm section must keep the cell isolated from circuitry, as required by SAF-002. Moving LEDs on the front does not make room for rear components.

The [captured-part space screen](component-space-screen-2026-10-05.md) now adds the other 151 coupon footprint instances to this trial geometry. Its initial outside-only packing result was deliberately conservative because a mechanically supported, wired battery may hover above insulated PCB components. A conditional 0402-under-pack screen improves the area budget, but neither scenario establishes the full-board fit.

## Next layout work

1. Source the missing dimensioned GCT cutout reliefs and agree on the 0.80 mm connector-compatible board thickness and process with the assembler.
2. After the unfinished power schematic is captured, generate the *entire* real netlist/footprint set and make a preliminary KiCad board with actual front/rear footprints. Place the real pack drawing with wire exit, protection and clearance, and reserve the antenna/switch/button/case zones.
3. Run native board DRC, power and signal routing feasibility, exact-parts PCBA review and STEP assembly checks. Resolve the affected last-column LED rows nearest USB with real mating geometry; require independent Gate A engineering review before fabrication.

**No PCB or cell was ordered.** The drawing is suitable for discussing envelope risks only.

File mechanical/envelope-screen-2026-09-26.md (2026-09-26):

<!-- SPDX-License-Identifier: CERN-OHL-S-2.0 -->

# Badge envelope and battery thickness screen

2026-09-26. Calculated feasibility screen for the **final 48 × 16 badge**, not a CAD fit, selected pack, protection design or permission to make a case mold. The physical limits are 110 × 35 × 11 mm including the case. This screen is independent of the unfinished charger actuator and can inform the preliminary PCB placement and eventual CadQuery model.

## Display geometry and usable width

At 1.95 mm pitch, the 48 × 16 centres span 91.65 × 29.25 mm. A 1.55 × 1.50 mm QBLP1515 package extends the envelope to approximately **93.20 × 30.75 mm** (assuming each package is centred on its pixel). That leaves only **16.80 mm total along length** and **4.25 mm total across width** between the package envelope and the maximum case outline. These are differences of outer dimensions, **not PCB-edge or component placement clearance**. With a centred display, width allocation is 2.125 mm per side for wall, optical lip and tolerances. The alternative 1010 LED may shrink its own package envelope, but cannot justify a reduced pixel pitch or a smaller nominal luminous aperture without Gate B selection.

For a *trial* 1.0 mm wall on both long sides and 0.5 mm cell side clearance on each side, the rectangular internal battery-width ceiling is `35 - 2×1.0 - 2×0.5 = 32.0 mm`. This is a provisional geometry budget; structural strength, print error, fasteners, USB/antenna placement and pack swelling may require more clearance. A nominal 34.8 mm-wide Jauch cell cannot fit that illustrative envelope. The [GlobTek 700 mAh terminated-pack drawing](https://www.globtek.com/pdf/manual-datasheets/BL0750F5030481S1PCTC.pdf) permits **31.0 mm maximum width** (30.5 + 0.5), leaving 1.0 mm inside this trial width budget before additional package/assembly variance or swelling allowance beyond the stated 0.5 mm per side. It cannot overlap M2 bosses, magnets or the FPC antenna zone.

## Illustrative section through LED, PCB and cell

The following single-stack assumption deliberately includes a local swelling allowance. The assumptions are **not selected wall/PCB/pack specifications**. Battery protection circuitry, leads and connectors may form a separate local maximum, so a pack thickness alone is insufficient.

| Layer, front to rear | Trial allowance (mm) | Basis or uncertainty |
|---|---:|---|
| Replaceable diffuser | 0.6 | Inside the plan's 0.5–0.8 mm trial range |
| LED-to-diffuser optical gap | 0.5 | Trial value; optics and physical stops unmeasured |
| QBLP1515 above front PCB surface | 1.2 | QT Brightek drawing says 1 mm height with ±0.2 mm general dimension tolerance; confirm drawing stack/assembly height |
| PCB | 0.8 | Trial stack-up, not an assembler commitment |
| Electrical/mechanical isolation behind PCB | 0.3 | Trial film/barrier allowance; validate where solder and vias face cell |
| Cell swelling/installation allowance | 0.5 | Trial reserve; pack vendor must define required clearance |
| Rear shell under cell | 1.0 | Trial printed shell wall |
| **Non-cell subtotal** | **4.9** | Leaves **6.1 mm** of the 11 mm maximum for the **entire pack** in this section |

| Candidate battery envelope | Calculated total using above stack (mm) | Status |
|---|---:|---|
| 5.6 mm maximum protected GlobTek 700 mAh pack thickness (5.3 + 0.3) | 10.5 | 0.5 mm apparent margin; poor six-hour and peak-current fit for full badge; protection PCB/wires may create thicker local zones |
| 6.0 mm protected GlobTek 800 mAh pack thickness | 10.9 | 0.1 mm apparent margin before board/solder/print/pack tolerances; five-pin integrated-gauge pack and 400 mA charge limit remain unresolved |
| 6.3 mm EEMB 900 mAh **bare cell** page thickness | 11.2 | Exceeds this trial stack by 0.2 mm **before** pack protection, NTC, wrap or connector |

The last two results are **layout risks**, not proof that thinner alternatives fit. Local staggering of tall circuitry and the cell may change the true section, but a cavity touching a pouch or pushing on components is forbidden. A lower LED height applies only if the selected LED and optical design support it; mixed-height coupon results do not authorize a final LED change. Do not shrink swelling clearance merely to force the arithmetic under 11 mm.

## 900 mAh source discrepancy and runtime

The [EEMB LP603048 product page](https://www.eemb.com/product-146) lists a **900 mAh bare cell** measuring 30.5 × 32.0 × 6.3 mm. [EEMB's part-number explanation](https://www.eemb.com/faq-6) decodes `603048` as *nominal* 6 × 30 × 48 mm (thickness × width × length) and explicitly excludes PCM and assembly. Those manufacturer statements conflict on the cell length; the source's 32.0 mm is therefore **unverified** for fit planning. The cited bare-cell page also does not specify a protected NTC-equipped terminated pack or its maximum charge/discharge currents. Obtain the exact manufacturer cell drawing and terminated-pack drawing before freezing a pouch outline. The earlier project plan repeats the page's 32 mm value as a candidate and should not be used as a final fit dimension.

With the project's provisional **0.45 W reference load**, 3.7 V nominal and 85% usable-energy assumption, a nominal 900 mAh cell gives `(0.900 Ah × 3.7 V × 0.85) / 0.45 W ≈ 6.29 h`. This is a **calculated model**, only about 0.29 h beyond the rough six-hour goal, before cell aging or measured variation. A drawing that resolves the cell size would still leave charge rating, peak discharge, NTC curve, connector polarity and heat to qualify.

## Next independent work

1. Make a parametric preliminary PCB footprint/antenna/USB outline and import the exact selected *terminated-pack* STEP or maximum drawing, with protection and lead exit included. The PCB STEP is not available yet.
2. Print a section gauge with the trial 5.3/6.0/6.3 mm cavity blocks and 0.5 mm nominal swelling allowance; use inert mockups, **not a compressed LiPo**, for this fit experiment.
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

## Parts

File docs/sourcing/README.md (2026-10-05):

<!-- SPDX-License-Identifier: CERN-OHL-S-2.0 -->

# Sourcing records

Candidate-part comparisons, supplier correspondence, exact pack drawings and frozen quote BOMs belong here. Marketplace listings demonstrate possible availability only; a part becomes approved only after its manufacturer, exact MPN, datasheet, package, pinout and relevant safety/optical documentation are verified.

Critical ICs should come from manufacturer-authorized distribution or a traceable assembler supply chain. Anonymous marketplace LiPo cells and silent PCBA substitutions are prohibited.

## Current records

- [Coupon Rev A core component candidates](coupon-rev-a-core-candidates.md) — exact schematic candidates, preliminary charger math, marketplace policy and unresolved Gate A items; not a frozen BOM.
- [2026-10-05 protected two-wire pack screen](pack-screen-2026-10-05.md) — board-NTC sourcing direction, leading 950 mAh technical candidate and orderability limits.

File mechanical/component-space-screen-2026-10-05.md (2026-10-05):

<!-- SPDX-License-Identifier: CERN-OHL-S-2.0 -->

# Preliminary component-space screen

The [rear packing trial](review/component-space.svg) and [machine-readable inventory](review/component-space.json) answer whether the current 106 × 32.5 mm **final-badge trial board** has obvious room for the parts already captured in the **16 × 16 coupon** schematic. Regenerate them from the current native KiCad netlist and project-local footprint courtyards with:

```sh
python3 tools/screen-final-component-space.py --output mechanical/review
```

This is a two-dimensional screen, not a KiCad PCB, routed design, DRC, complete final-badge netlist or pack fit. It replaces the coupon's 256 mixed LEDs with a trial 768 front QBLP1515 array and its one TLC59581 body with three on the rear; the final LED remains a Gate B choice. It carries the other 151 captured footprint instances over as a **provisional trial inventory**; some coupon test pads may be omitted on a final board, while extra support parts for the two added drivers are absent. The 20 test pads have 1.0 mm physical pads but no courtyard, so the trial assigns each a 1.5 × 1.5 mm reservation. The initial screen puts all small captured components on the rear **outside** the centred `LP503055` finished-body outline. This is deliberately restrictive: the pack is a separate wired assembly held by the enclosure, and insulated PCB components may be possible beneath it. The board-facing battery NTC is still an XY target, not an exact footprint.

| Area accounting | mm² |
|---|---:|
| Trial board | 3445.00 |
| `LP503055` finished body (56 × 30.5 mm) | 1708.00 |
| MCU, three driver courtyards and on-board portion of USB courtyard | 736.71 |
| Area outside those large reservations | **1000.29** |
| Other captured courtyards plus trial test-pad reservations | **901.60** |
| Nominal remainder before any part-to-part clearance, routing or missing parts | **98.69** |

The largest remaining groups are 16 row P-MOSFETs (207.2 mm²), 16 row N-MOSFETs (190.4 mm²), 62 resistors (124.0 mm²), and the row decoder (63.9 mm²). A deterministic first-fit trial on a 0.25 mm grid, with just 0.25 mm around each small reservation, puts **55 of 151** outside the pack outline and leaves **96** unplaced. This failure reflects the restrictive placement rule and the simple packing algorithm; it does **not** prove that the board lacks room.

## Correction: conditional under-pack placement

The owner correctly pointed out that the battery is not soldered to the PCB. A second, deliberately optimistic XY screen treats the 62 captured 0402 resistors and 15 captured 0402 capacitors as *candidates* for placement beneath a supported, insulated pack. Their 77 courtyards total **154.0 mm²**. Moving those reservations into the battery-facing region raises the nominal outside-area remainder from 98.69 to **252.69 mm²**; the first-fit pass then leaves **22 of 74** outside components unplaced. Those 22 are 15 of the 16 row N-MOSFETs plus L1, U35, C42/C43, U36, U32 and U31. This is an artifact of the simple placement order and crowded side strips, **not a proof those components cannot fit**. The run does not consider electrical grouping or routing. Decouplers and row-gate parts may need to remain beside the devices they serve, and the pack centre is reserved for the provisional NTC target.

The 11 mm section stack currently has only **0.8 mm nominal headroom** above the `LP503055` maximum body thickness. Component assembled height, solder, insulating cover, pouch support, swelling, tolerance and temperature coupling must all be checked before any footprint is actually placed under the pack. The case thickness may ultimately need to increase, but the first outside-only area screen did not establish that. Equally, it does not establish that reducing resolution or component count is necessary.

The absent circuit is substantial: input protection, charger, battery connector and strain relief, VLED converter, temperature-sensor footprint and network, final gauge isolation, display interlock, two additional LED-driver support networks, antenna/cable zone, mounting features and all copper/routing. In the outside-only baseline, omitting all 20 coupon test-pad reservations would increase the nominal remainder to **143.69 mm²**. The `LP503055` drawing omits wire exit, connector and possible protection-board protrusion beyond its body. The [trial section stack](envelope-screen-2026-09-26.md) totals 4.9 mm outside the cell; with this pack's 5.3 mm maximum body thickness it reaches 10.2 mm within an 11 mm case. The rightward driver move removes one body/courtyard overlap but does not settle the rest of the placement.

**Disposition:** The existing screens do not establish either a fit or a no-fit result. Keep the 106 × 32.5 × 11 mm target for a more realistic trial: model the supported battery above the board, place low-profile candidate parts beneath it only with a verified height/insulation stack, keep warm/tall parts and required local decouplers in appropriate zones, then place the complete netlist in KiCad and run DRC. Do not relax the product requirements based solely on the original outside-only packing result. Independent Gate A review and the exact protected pack remain required before fabrication.

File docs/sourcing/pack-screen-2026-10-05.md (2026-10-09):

<!-- SPDX-License-Identifier: CERN-OHL-S-2.0 -->

# Protected two-wire pack screen, 2026-10-05

The owner accepted a **trial board-mounted battery-facing NTC** under [ADR 0019](../decisions/0019-board-mounted-battery-temperature-sensing.md), with cell-to-board thermal validation before battery/board freeze. This permits two-wire packs without bypassing hardware temperature qualification. ADR 0024 now selects the exact `LP452845`/PHR-2 drawing as the Rev A design target; no battery is ordered or qualified. Dimensions and ratings below are manufacturer/distributor claims; runtimes are calculations, not measurements.

The provisional finished-pack envelope is ≤32.0 mm wide and ≤6.1 mm thick. The reference calculation uses 0.45 W, 3.7 V nominal and 85% usable energy. The existing modeled full-white case is 2.49 W, or 0.83 A at 3.0 V, before transient margin. All final dimensions require CAD fit, including the protection board, wire exit, connector and swelling space.

| Exact configuration | Evidence and fit | Electrical/use finding | Availability and disposition |
|---|---|---|---|
| LiPol `LP503055`, protected 950 mAh, two wires **without connector** | [Manufacturer drawing FD_3055_73, index 4](https://www.lipolbattery.com/LiPo-Battery-Datahseet/LiPo_Battery_LP503055_3.7V_950mAh.pdf): finished pack 55 ±1 × 30 ±0.5 × 5.0 ±0.3 mm, ~19 g, 4.2 V charge, 475 mA max charge, 950 mA continuous discharge. It is not an NTC pack. | Calculated ~6.64 h reference runtime. 0.95 A continuous limit is 0.12 A above the 0.83 A model, before transients. The proposed 2.49 kΩ ISET ceiling of ~396 mA would be below the listed 475 mA charge maximum **if** exact-pack temperature/thermal qualification succeeds. | **Technical comparator, not the Rev A design pack.** [Manufacturer listing](https://li-polymer-battery.com/3-7v-rechargeable-li-polymer-battery-lp503055-950mah-with-pcm-and-wires/) advertises five-piece sample MOQ and optional connector, but the drawn stock configuration has bare wires and no live stock/price. Obtain an exact keyed-connector assembly code, max local envelope, pin polarity and supply quote before BOM selection. |
| LiPol `LP452845`, protected 900 mAh with JST PHR-2, no NTC | [Finished-assembly drawing FD_6225_10 index 1](https://www.lipobattery.us/wp-content/uploads/2022/08/LP452845-3.7V-900mAh-with-JST-PHR-2.pdf), found 2026-10-09: 47 × 28.5 × 4.8 mm maximum body, AWG 26 leads, 450 mA maximum charge and 900 mA maximum discharge. | Calculated ~6.29 h reference runtime. “Maximum discharge” is not specified as continuous; only 0.07 A nominal headroom over modeled full-white draw. | **Selected Rev A design target under ADR 0024, not yet qualified or ordered.** Drawing now resolves body/connector identity, but stock, price, exact mated polarity, continuous discharge and charge-through behavior remain unconfirmed. [Swap screen](../../mechanical/lp452845-swap-screen-2026-10-09.md) finds no PH pocket with original anchors, but one conditional pocket in the proposed dual-row-package layout. |
| Akyga `AKY0108` / `LP603048`, protected 850 mAh with JST SYP-02T-1, no NTC | [Distributor listing](https://elektronik.ropla.eu/en/magazyn/magazyn/?ic=AKY0108) shows stock and two-piece MOQ. The [manufacturer sheet](https://elektronik.ropla.eu/pdf/stock/aky/aky0108.pdf) specifies **finished assembly 50.5 × 31 × 6.5 mm max**, despite a 6.0 mm cell. Max discharge is 1C = 0.85 A. | Calculated ~5.94 h reference runtime; only 0.02 A headroom over modeled full-white draw. | **Exclude under current 6.1 mm pack-thickness budget.** A catalog's “6.0 mm” is a cell dimension, not a finished-pack fit. |
| GlobTek `BL0750F5030481S1PCTC`, protected 700 mAh with 3-pin NTC connector | [Manufacturer drawing](https://www.globtek.com/pdf/manual-datasheets/BL0750F5030481S1PCTC.pdf): 50.5 × 31.0 max × 5.6 max mm, 700 mA continuous discharge and max charge. [DigiKey listing](https://www.digikey.com/en/products/detail/globtek-inc/BL0750F5030481S1PCTC/16515787) showed 1,638 in stock at $11.85 each when checked. | Calculated ~4.89 h reference runtime; 0.70 A continuous limit is below modeled 0.83 A full-white draw. | Best documented immediately orderable **coupon** pack, not a qualified final-badge pack. Manufacturer drawing alternates `BL0700`/`BL0750` strings and omits NTC curve. |

Next sourcing decision: ask LiPol for current stock, a quote, connector polarity and a continuous discharge rating for the exact `LP452845`/PHR-2 assembly. In parallel, request an exact keyed-connector assembly code and revised drawing for `LP503055`, or find a distributor-stocked equivalent with documented finished dimensions and continuous discharge margin above the modeled 0.83 A full-white draw. A connector option is a distinct assembly, not a silent substitution for the drawn bare-wire part. The PCB NTC must pass ADR 0019's cell-to-board comparison. No charger-current ceiling is raised by this screen.

**2026-10-06 availability recheck:** DigiKey still lists the exact GlobTek coupon-only part as [in stock](https://www.digikey.com/en/products/detail/globtek-inc/BL0750F5030481S1PCTC/16515787). Two other orderable possibilities do not replace the final-pack inquiry: Jauch's 950 mAh [LP523450JU family](https://www.jauch.com/en-US/products/battery_technology/getPrm/batteries/Lithium%20Polymer%20Batteries/) is 34.8 mm wide before a connector, beyond the provisional 32.0 mm battery-width ceiling; TinyCircuits [ASR00036](https://files.tinycircuits.com/Datasheets/ASR00036_850mAh.pdf) is 850 mAh but allows only 0.425 A continuous charge/discharge and its [finished thickness range](https://tinycircuits.com/products/copy-of-lithium-ion-polymer-battery-3-7v-850mah) reaches 6.5 mm. The GlobTek pack is therefore still the only immediately orderable coupon candidate in this screen, while LP503055 remains the leading final-badge inquiry. Stock is time-sensitive; this is a sourcing observation, not a pack selection or purchase authorization.

**2026-10-09 drawing correction:** LiPol's exact [LP452845 JST PHR-2 assembly drawing](https://www.lipobattery.us/wp-content/uploads/2022/08/LP452845-3.7V-900mAh-with-JST-PHR-2.pdf) is available. It makes this the best *documented connectorized fit candidate* so far, while `LP503055` retains a higher stated continuous-discharge rating and slightly higher modeled runtime. Neither has confirmed current stock or a fully qualified final-badge discharge/thermal/connector fit. Do not interpret the seller's conditional one-week sample lead time as confirmed availability.

**2026-10-09 design decision:** [ADR 0024](../decisions/0024-lp452845-pack-and-temperature-window.md) chooses the exact LP452845/PHR-2 assembly for source capture and adds a battery-facing hardware 15/40 °C charge-permission guard. This resolves which pack to design around; it does not assert a continuous 900 mA rating, stock, physical fit or a validated cell-to-board temperature bound. The [revised swap screen](../../mechanical/lp452845-swap-screen-2026-10-09.md) uses the actual JST footprint courtyard rather than the too-small provisional PH pocket.

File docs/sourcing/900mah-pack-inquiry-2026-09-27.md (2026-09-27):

<!-- SPDX-License-Identifier: CERN-OHL-S-2.0 -->

# Manufacturer inquiry: protected thin 1S 900 mAh pack

Status: **request specification; do not order**. This is a requirements sheet for LiPol or another identified pack manufacturer, not a qualified battery or confirmed supplier offer. Based on [ADR 0016](../decisions/0016-runtime-and-fit-over-charge-speed.md) and the [pack shortlist](pack-shortlist-2026-09-27.md). The published `LP452845` two-wire pack is only a starting point; a three-wire version requires its own exact order code and revision-controlled drawing. A 700 mAh coupon battery may be procured separately once its documented charger configuration is reviewed.

## Product envelope and use

| Item | Request to manufacturer | Reason |
|---|---|---|
| Capacity and chemistry | Nominal ~900 mAh 1S Li-ion polymer; supply minimum guaranteed delivered capacity, test rate/temperature and cycle-life criteria | Six hours needs ~859 mAh nominal under the **provisional** 0.45 W / 85% usable model; 900 mAh gives only ~6.29 h mathematically |
| Installed geometry | Maximum dimensions **including cell, protection board, wrap, tabs and lead exit**, with tolerances and local peaks; trial ceiling 32.0 mm width, 6.1 mm thickness, length to be confirmed against placement | Trial case is 110 × 35 × 11 mm externally; a bare-cell 4.5 mm measurement does not qualify the pack; keep attachment and swelling clearance |
| Weight | Maximum assembled weight including leads/connector, aiming under 21 g battery allocation; provide real worst-case value | Finished badge must remain under 100 g |
| Discharge | State *continuous* discharge rating at low cell voltage and operating temperature, plus duration/conditions for any peak rating; provide protection trip values | Provisional full-white demand ~0.83 A at 3.0 V before transients; published 900 mA `LP452845` maximum lacks explicit continuous qualification |
| Charge | State maximum continuous CC current, CV voltage/tolerance, precharge profile and temperature derating; supply charge-time curve or test conditions if available | Published `LP452845` lists max 450 mA; 80% at that rate has an ideal **96 min minimum** before taper or system load. A slower safe charge is acceptable |
| Temperature sense | Integral **10 kΩ NTC**, its B value/tolerance, location, wiring and allowable charge-temperature window; confirm compatibility data for external charger TS threshold design | Hardware charge permission must work without firmware and with the actual cell temperature |
| Protection and OFF drain | Supply PCM overcharge/overdischarge/short-circuit/overcurrent thresholds, reset conditions and maximum protection quiescent current across voltage/temperature | Whole badge OFF goal <50 µA including protection and charger/switch leakage |
| Connector | Three-wire connector housing and mating header exact MPNs; cavity numbering, connector viewing orientation, BAT+/BAT−/NTC mapping, polarity and wire gauge/length | Avoid mating reversal or selecting a PCB footprint from a two-wire listing |
| Traceability | Exact *finished assembly* ordering code and dated, revision-controlled drawing, UN 38.3 test summary and available IEC/UL assembly evidence, lot marking and transport documentation | Gate A and PCBA source control |
| Purchasing | Sample and production MOQ, unit pricing at 5/25/100, quoted lead time, shipping into the US, reorder route and any tooling/NRE | Development quantity and follow-on reproducibility |

Ask explicitly whether a three-wire protected 900 mAh `LP452845` derivative is possible **within the entire finished-pack** width/thickness caps, and whether any alternate off-the-shelf exact assembly already meets these conditions. Request drawings before samples. If impossible, ask what dimension or current criterion is limiting; then reopen the case or runtime trade-off with the owner. Do not infer a new NTC variant's availability or ratings from the published two-wire listing.

## Design response when documents arrive

1. Cross-check manufacturer identifier, drawing revision, dimensions at PCM/lead exit and pack weight against the current mechanical section and full weight rollup; update trial CAD before freezing battery location.
2. Recompute six-hour reference runtime and full-white low-voltage current using documented minimum capacity and discharge limits, then use coupon measurements for final claims.
3. Choose a documented exact ISET resistor with a worst-case programmed maximum **below the pack's derated charge rating**. Verify charger TS network, safety timer, USB port budget and worst-case thermal dissipation; publish provisional pack-specific 80%/full timing before Gate A.
4. Confirm connector mating polarity from both manufacturer's pin view and the PCB footprint. Capture the exact pack and header in KiCad, run native ERC/netlist/DRC, then obtain independent Gate A review before any assembled-board/battery order.

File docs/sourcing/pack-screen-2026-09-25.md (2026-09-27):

<!-- SPDX-License-Identifier: CERN-OHL-S-2.0 -->

# Single-cell pack screening, 2026-09-25

Historical timing comparison: [ADR 0016](../decisions/0016-runtime-and-fit-over-charge-speed.md) withdrew the 45–60 min / 75–100 min targets on 2026-09-27. The arithmetic below still screens safe current but no longer disqualifies a pack solely for slower charging.

These are documented **candidates**, not approved pack MPNs, a purchase list or permission to fabricate. Compare the terminated pack, not just the bare cell. Both 800 mAh and 700 mAh nominal alternatives illustrate why the current charge setting cannot be frozen ahead of pack selection. The owner prefers a US distributor for development batteries; DigiKey is a potential channel, but domestic stocking does not mean a cell was manufactured in the US.

| Exact terminated pack | Documented properties | Disposition |
|---|---|---|
| GlobTek `BL0750F5030481S1PCTC` | Manufacturer drawing Rev D: nominal **700 mAh** despite `0750` in the ordering code; protected 1S pouch, 10k NTC, three-wire Molex 51021-0300, **50.5 × 30.5 (+0.5) × 5.3 (+0.3) mm**, approximately 22 g. Maximum charge **1C = 700 mA**, continuous discharge 1C = 700 mA. Manufacturer drawing has an internal part-number inconsistency on page 2 (`BL0700...`), and does not establish the NTC B value in the reviewed electrical table. | Documented US distributor candidate for a **coupon-only revised charge setting**, subject to manufacturer confirmation of the exact drawing, NTC curve, protection circuit and connector polarity. Draft charge ceiling 872 mA exceeds pack maximum by **172 mA**. Full-badge peak modeled load exceeds its continuous discharge rating. |
| GlobTek `BL0800F5424651S1PSXH` | Manufacturer drawing Rev F1: 800 mAh, protected, 10k NTC with B = 3950 K and integrated BQ27542 fuel gauge, 24 × 71 × 6 mm, approximately 30 g. Maximum charge **0.5C = 400 mA**; continuous discharge 1.4 A. Five-wire Molex 51021-0500 exposes pack I²C. | Fits bounding box, but duplicates the planned on-board MAX17048, adds a five-pin battery interface and requires charger limit ≤400 mA. At 30 g it leaves 45 g for all other items under the 75 g stretch goal. Do not substitute it into the draft. |
| LiPol `LP402480` configured with PCM/NTC/Molex 78172-0003 | Manufacturer page: 800 mAh; cell 4 × 24 × 80 mm, pack listed 16 g; protected, NTC, maximum charge 400 mA and discharge 800 mA. Stock is quote-dependent, and the 4 × 24 × 80 mm specification is described as **cell** size, not a verified maximum terminated-pack envelope. | May help later if measured mass dominates, but charging limit and connector require revisions; pack dimensions, NTC curve, current peaks and US supply have not been established. |

## Calculation and implications

The existing BQ24074 ISET network has a calculated **0.698–0.872 A** charge-current range under the repo's retained programming-error assumptions. The 700 mAh GlobTek part is rated at no more than 0.700 A; the other two packs at no more than 0.400 A. Normal temperature regulation or input current limiting is not a valid substitute for setting a safe maximum charge current. Select the exact pack and protection/NTC evidence before choosing the final ISET resistor or claiming the 45–60-minute 80% goal.

`python3 tools/check-power-design.py --candidate-iset-ohm 1500 --pack-max-charge-ma 700` calculates **526–657 mA** and passes *only* the charge-current ceiling for the 700 mAh candidate. At 800 mAh / 400 mA, `--candidate-iset-ohm 2490 --pack-max-charge-ma 400` calculates approximately **317–396 mA** and passes that same limited check. Both resistor values are numerical screening targets, **not selected resistor MPNs or charger updates**. The current 1130-ohm ISET fails either candidate. The tool refuses missing, nonfinite or out-of-range inputs; it does not check thermistor trip temperatures or battery capacity.

The 45–60-minute 80% target in CHG-001 also needs screening independently of charger safety. Even assuming a constant maximum current from zero to 80% state of charge, no taper, no input/thermal limiting and no system load, the 800 mAh pack limited to 400 mA needs **at least 0.8 × 800 / 400 × 60 = 96 minutes**. The 2.49 kΩ proposal is slower still: its most optimistic 396 mA corner gives approximately **97 minutes**. Thus that exact pack cannot meet CHG-001's 60-minute upper target under the documented 400 mA charge limit. For the 700 mAh candidate, the 1.50 kΩ proposal gives an ideal **51–64-minute** range at its 657–526 mA calculated corners. A 60-minute result requires at least 560 mA *average battery charge current* over that interval; even the ideal constant-current arithmetic misses this at the 526 mA corner. Real precharge, CV taper, PowerPath load, thermal regulation and reduced usable capacity change observed timing, so neither candidate is a demonstrated charging-speed solution. If the 400 mA pack is eventually selected, formally revisit CHG-001 before claiming compliance; never raise its current to force the target.

Energy-only upper bounds at nominal capacity are **2.59 Wh / 6 h ≈ 432 mW** for the 700 mAh pack and **2.96 Wh / 6 h ≈ 493 mW** for an 800 mAh pack. These are gross power ceilings before converter losses, usable-depth limits, pack aging and any case/LED measurements. Neither number establishes six-hour runtime. The preliminary layout must include actual wrap and lead exit, mounting, swelling clearance and the three-pin keyed plug; nominal pouch dimensions alone are not a mechanical fit sign-off.

Using the existing [project-plan runtime model](../project-plan.md) rather than gross energy alone, the 35%-lit/25%-brightness reference case is approximately 0.45 W at the battery and assumes 85% usable nominal energy. The resulting **calculated** times are about **4.9 h for 700 mAh** and **5.6 h for 800 mAh**. The 700 mAh pack's documented capacity and discharge ceiling therefore make it a useful **coupon-only** dimensional/charger candidate, but it is not a demonstrated six-hour full-badge pack. Changing user-selected brightness or measured component efficiency could change these numbers; no automatic dimming is proposed.

There is a separate peak-load exclusion for the **full** badge: the same model estimates **2.49 W** at the battery for full-white brightness. At 3.0 V this implies **0.83 A** before transient and aging margins, exceeding the 700 mAh GlobTek pack's **0.70 A maximum continuous discharge**. Its PCM overcurrent threshold (1–4 A) does not enforce the lower continuous rating. Do not use that pack for an unrestricted full-badge build at the present display power. The coupon has only 16 columns and requires its own measured peak-current review; no final brightness or discharge claim follows from this screening. The 800 mAh GlobTek drawing specifies 1.4 A continuous, but its 400 mA charge maximum and 30 g mass remain major trade-offs.

As of this screening, DigiKey displayed 1,640 units of `BL0750F5030481S1PCTC` at $11.85 for one and an 18-week manufacturer standard lead time. Stock/price are snapshots, not reservations. Do not order now; an exact pack, revised charger setting and Gate A must precede the PCB release. The battery for an **isolated development test** can be chosen separately if its charger settings are explicitly compatible.

## Capacity floor and a near miss

Under the same provisional 0.45 W reference load, 85% usable energy and 3.7 V nominal voltage, six hours requires at least **0.45 W × 6 h / (3.7 V × 0.85) ≈ 859 mAh** nominal capacity. This is an arithmetic floor, not a pack specification: aging, voltage sag and a measured workload may demand more. Full-white screening separately requires at least **0.83 A continuous discharge at 3.0 V**, before peak margin. A pack's PCM trip threshold cannot replace its lower continuous rating.

Jauch `LP523450JU+PCM+MOLEX 51021-0300 70MM` is a US-distributor near miss. DigiKey lists 950 mAh, 34.5 mm pack width and a three-position connector. Jauch's catalogue gives **34.8 mm cell width**. That leaves only 0.2 mm inside the 35 mm *outside* case width even before walls, tolerances or swelling allowance. The manufacturer's available two-wire variant sheet states up to 1.0 A charge/discharge under specified temperature conditions, but it does not establish an NTC or the precise three-wire pack wiring. Exclude it from the current mechanical design rather than assuming that nominal capacity alone makes it a fit.

## Evidence

- [GlobTek 700 mAh drawing Rev D](https://www.globtek.com/pdf/manual-datasheets/BL0750F5030481S1PCTC.pdf), pages 3 and 5, and [DigiKey listing](https://www.digikey.com/en/products/detail/globtek-inc/BL0750F5030481S1PCTC/16515787), inspected 2026-09-25.
- [GlobTek 800 mAh drawing Rev F1](https://www.globtek.com/pdf/manual-datasheets/BL0800F5424651S1PSXH.pdf), pages 3–4, and [DigiKey listing](https://www.digikey.com/en/products/detail/globtek-inc/BL0800F5424651S1PSXH/14318830), inspected 2026-09-25.
- [LiPol 800 mAh manufacturer page](https://www.lipobattery.us/un38-3-iec62133-msds-certified-lipo-battery-lp402480-800mah-3-7v-2-96wh-with-pcm-ntc-wires-molex-78172-0003/), inspected 2026-09-25.
- [Jauch battery catalogue](https://www.jauch.com/en-GB/products/battery_technology/getPrm/batteries/), [two-wire variant sheet](https://www.jauch.com/downloadfile/5bf529f04a63911ea283ee57b9c7f2385/950mah_-_lp523450ju_1s1p_2_wire_70mm.pdf) and [DigiKey three-position listing](https://www.digikey.com/en/products/detail/jauch-quartz/lp523450ju-pcm-molex-51021-0300-70mm/21765435), inspected 2026-09-25. The two-wire sheet is not evidence for the three-wire pack's NTC.
- [Existing BQ24074 programming analysis](../../hardware/coupon/rev-a/power-pre-capture.md); this screen does not redo its resistor/source verification.

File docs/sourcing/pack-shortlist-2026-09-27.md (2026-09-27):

<!-- SPDX-License-Identifier: CERN-OHL-S-2.0 -->

# Pack selection checkpoint, 2026-09-27

**Decision: no final pack or charger ISET MPN is yet qualified.** Under [ADR 0016](../decisions/0016-runtime-and-fit-over-charge-speed.md), pursue the LiPol 900 mAh family as the leading *final-fit inquiry* despite a longer safe charge. The 700 mAh GlobTek pack remains a conditional *coupon-only* candidate. Do not interchange the two pack connectors or current settings. All values below are manufacturer/distributor claims or calculations, not measurements.

## Screen against current project constraints

For the **final** 48×16 badge the trial mechanical section allows an entire terminated pack at most **6.1 mm** thick, and a trial pack-width ceiling of **32.0 mm** after case walls and side clearances. These are provisional and omit detailed PCM/lead exit, attachment and assembly fit. The provisional 0.45 W reference load at 3.7 V and 85% usable nominal energy gives a **~859 mAh arithmetic floor** for six hours; the modeled 2.49 W full-white load needs about **0.83 A at 3.0 V**, before transient margin. The former 80% in 45–60 minutes / full in 75–100 minutes targets were withdrawn by ADR 0016; pack-specific times require documentation and measurement.

| Candidate (exact listed configuration) | Evidence | Calculated / physical finding | Status |
|---|---|---|---|
| GlobTek `BL0750F5030481S1PCTC` protected 700 mAh pack | [Rev D pack drawing](https://www.globtek.com/pdf/manual-datasheets/BL0750F5030481S1PCTC.pdf) gives 50.5 × **31.0 max** × **5.6 max** mm, ~22 g, 10k NTC, Molex 51021-0300 (pins 1 BAT+, 2 BAT−, 3 NTC), maximum 700 mA charge and 700 mA continuous discharge; [DigiKey](https://www.digikey.com/en/products/detail/globtek-inc/BL0750F5030481S1PCTC/16515787) listed 1,638 in stock at $11.85 each on 2026-09-27. | ~4.89 h at reference workload. Full-white 0.83 A model exceeds its 0.70 A continuous rating. Existing 1.13k ISET worst corner ~0.872 A exceeds charge rating; 1.50k numerical setting is ~0.526–0.657 A, with no NTC/thermal qualification. | **Coupon-only conditional.** Manufacturer drawing alternates `BL0700...` and `BL0750...` part strings and does not specify the NTC curve/tolerance. Confirm exact configuration and TS mapping before capture/order. |
| LiPol `LP452845` currently listed protected two-wire JST PHR-2 version | [Manufacturer listing A](https://www.lipobattery.us/900mah-lipo-battery-lp452845-3-7v-900mah-3-33wh-with-protection-circuit-and-wires-50mm-and-jst-phr-2/) says 900 mAh, 4.5 × 28 × **46** mm, ~18 g, 450 mA maximum charge, 900 mA maximum discharge, **no NTC**; [manufacturer listing B](https://www.lipoly-battery.com/900mah-lipoly-battery-lp452845-3-7v-3-33wh-with-pcm-wires-connector-jst-phr-2/) gives **45** mm length and offers an NTC/custom connector configuration. | Nominal-cell arithmetic ~6.29 h at 0.45 W (only 0.29 h margin). At the stated 450 mA maximum, **at least 96 min to 80%** and 120 min to full even under ideal constant-current/no-taper assumptions. 900 mA listed maximum discharge leaves only 70 mA over modeled 0.83 A, and is not explicitly a guaranteed continuous rating. | **Leading final-fit manufacturer inquiry, not selected.** The actual two-wire variant fails pack-NTC requirement, and no exact three-wire NTC/PCM/connector assembly drawing, maximum envelope, continuous current or qualified pack datasheet was found. A custom configuration needs its **own exact orderable MPN**. Slower charging is accepted in principle under ADR 0016, subject to pack-specific planning/measurement. |
| LiPol `LP623048` protected 900 mAh, 10k NTC, wires, no connector | [Manufacturer listing](https://www.lipobattery.us/900mah-rechargeable-lipo-battery-lp623048-with-pcm-ntc-wires/) gives 6.2 × 30 × 48 mm, 450 mA maximum charge, 900 mA maximum discharge, ~18 g. | Stated **6.2 mm** thickness exceeds the provisional **6.1 mm** entire-pack allowance already, before a connector, tolerance or pack-local PCM peak. Same ideal ≥96 min to 80%. | **Exclude from current final mechanical design.** Reopen only after a real section layout creates enough clearance; slower charging alone is no longer a disqualifier. |
| Ufine `603048` 900 mAh with PCM, no NTC | [Manufacturer page](https://www.ufinebattery.com/products/3-7-v-900mah-lithium-ion-battery-603048/) states 900 mA maximum charge and discharge, ~18 g and 1S protection, but explicitly **NTC: No**. | Up to 900 mA charging could, in principle, support a faster charge than the 450 mA LiPol listing; the pack envelope and NTC-equipped variant are **not documented**. Its `603048` designation does not establish a finished protected-pack 6.0 mm height. | **Technical fallback inquiry only.** Require exact qualified three-wire pack drawing, charger and protection data before considering fit or BOM. |

The Jauch 950 mAh, ~34.8 mm-wide cell remains excluded by the 35 mm **outer** case width; the 800 mAh GlobTek pack with integrated fuel gauge still duplicates the onboard gauge and limits charging to 400 mA. See the [earlier pack screen](pack-screen-2026-09-25.md) for their exact source references.

## Evidence needed to select

Request **one revision-controlled PDF per exact terminated pack/order code**, including: maximum length/width/thickness over shrink-wrap and PCM plus lead-exit/connector local peaks and swelling/installation allowance; actual mass; 1S chemistry/maximum charge voltage; minimum and nominal delivered capacity at defined discharge/cutoff conditions; maximum charge current including temperature derating and continuous/peak discharge ratings; protection thresholds and OFF quiescent/leakage specification; 10k NTC B value, tolerance, physical location, ground-reference wiring and TS trip limits; connector housing/terminals and *front/back pin numbering/polarity*; safety/transport test evidence for that assembly, sample MOQ, US-shipped lead time and traceable supply. Specifically ask GlobTek to reconcile the `BL0700`/`BL0750` drawing labels and state the NTC curve, and ask LiPol whether an `LP452845` 3-wire NTC+PCM version is available with **max assembled thickness ≤6.1 mm**, **max width ≤32 mm** and an exact order code. Ask the supplier to state clearly whether 900 mA is continuous discharge and whether a higher safe charge rate exists for that *specific cell*; do not infer it from the bare-cell code.

Do not raise ISET, omit the pack NTC, squeeze the pouch to fit, or buy a hypothetical custom configuration. A coupon battery and final battery may be different **only with separate charger/TS configurations and documented board population**. No KiCad source or requirements changed in this sourcing screen. Next electrical step after receiving a qualified pack drawing: set the exact ISET/NTC/timer parts, verify worst-case input/thermal and charge-time corners, then capture pack connector and physical switch in KiCad for native review and Gate A.

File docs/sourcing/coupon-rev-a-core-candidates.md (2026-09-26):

<!-- SPDX-License-Identifier: CERN-OHL-S-2.0 -->

# Coupon Rev A core component candidates

**2026-09-17 resistor amendment:** [ADR 0012](../decisions/0012-programming-resistor-error-budget.md) selects `ERA2AEB3651X`, `ERA2AEB3481X` and `ERA2AEB1131X` (0.1%, 25 ppm/K). References below to 1% programming resistors are historical; current calculations retain ±1% as the total qualified resistance-error envelope. Nominal values and current ceilings do not change; assembly/service drift qualification remains open.

**2026-09-17 current-budget finding:** resistor ranges below include initial tolerance only. The [temperature-drift counterexample](../../hardware/coupon/rev-a/usb-supervision-capture.md) exceeds the configured-SDP allocation for an ordinary 100 ppm/K candidate. Precision-part qualification or revised lower limits are required before programming-resistor capture; no substitution or current increase is approved.

Status: researched candidates for schematic capture; **not a frozen BOM and not authorization to buy or fabricate**

Research cut-off: 2026-09-14 for the selected charger/input sources; 2026-09-06 for other candidates

## How to read this record

An exact MPN in this document means that its public documentation, package and at least one traceable purchase route were found. It does not mean its symbol, footprint, thermal design, surrounding passives, availability or use in this circuit has passed Gate A. Stock counts and prices are intentionally not frozen here because they can change between research and quotation.

Before schematic capture, every selected part receives a project-local symbol and footprint checked against the linked manufacturer drawing. Before release, the assembler must quote the exact MPN and disclose its source; no equivalent or house substitution is allowed without written review.

## Core silicon and switching

| Function | Exact schematic candidate | Package / implementation note | Manufacturer evidence | Traceable sample source | State |
|---|---|---|---|---|---|
| MCU and BLE | `ESP32-S3-WROOM-1U-N16R8` | External-antenna module; 16 MB flash, 8 MB octal PSRAM | [Espressif module datasheet](https://documentation.espressif.com/esp32-s3-wroom-1_wroom-1u_datasheet_en.pdf) | [DigiKey](https://www.digikey.com/en/products/detail/espressif-systems/ESP32-S3-WROOM-1U-N16R8/16162641) | [Exact library and controller source captured](../../hardware/coupon/rev-a/controller-capture.md); [native review passed](../development/controller-review-d56e1aa.md) |
| 48-channel LED sink | `TLC59581RTQT` | 56-pin `RTQ` QFN, 8 × 8 mm; one on coupon, three on final badge | [TI datasheet](https://www.ti.com/lit/gpn/TLC59581) | [DigiKey](https://www.digikey.com/en/products/detail/texas-instruments/TLC59581RTQT/6571953) | [Driver captured](../../hardware/coupon/rev-a/driver-capture.md); provisional RTQ0056E footprint; confirm supplied E/G variant |
| Standalone charger / power path | `BQ24074RGTR` | 16-pin `RGT` VQFN, 3 × 3 mm; linear PowerPath with hardware standby/100/500/external modes | [TI datasheet](https://www.ti.com/lit/gpn/BQ24074) | [DigiKey](https://www.digikey.com/en/products/detail/texas-instruments/BQ24074RGTR/2047269) | Selected by ADR 0010; exact library, circuit and thermal review pending |
| Historical charger library | `BQ25616JRTWT` | 24-pin `RTW` WQFN, JEITA variant | [TI datasheet](https://www.ti.com/lit/gpn/BQ25616) | [DigiKey](https://www.digikey.com/en/products/detail/texas-instruments/BQ25616JRTWT/11570504) | Exact library/native render passed, but direct input topology rejected by ADR 0009; not selected for capture |
| BC1.2 detector / USB data switch | `BQ24392RSER` | 10-pin `RSE` UQFN, 2.05 × 1.55 mm; VBUS-powered | [TI datasheet](https://www.ti.com/lit/gpn/BQ24392) | [DigiKey](https://www.digikey.com/en/products/detail/texas-instruments/BQ24392RSER/3471183) | Selected by ADR 0010; exact library and level/priority circuit pending |
| Application USB data isolator | `TS3USB31ERSER` | 8-pin `RSE` UQFN, 1.5 × 1.5 mm; switched-rail power and partial-power-down isolation | [TI datasheet](https://www.ti.com/lit/gpn/TS3USB31E) | [DigiKey](https://www.digikey.com/en/products/detail/texas-instruments/TS3USB31ERSER/2071792) | Selected by ADR 0010; exact library and high-speed routing pending |
| USB-C CC detector | `TUSB320LAIRWBR` | 12-pin `RWB` X2QFN; fixed UFP, GPIO mode | [TI datasheet](https://www.ti.com/lit/gpn/TUSB320LAI) | [DigiKey](https://www.digikey.com/en/products/detail/texas-instruments/TUSB320LAIRWBR/5722618) | [Exact library/native render passed](../../hardware/coupon/rev-a/power-library-audit.md); current-state circuit review pending |
| USB-only 3.3 V rail | `TLV75533PDBVR` | 500 mA SOT-23-5 LDO from VBUS; powers CC detector and its logic while application rails are off | [TI datasheet](https://www.ti.com/lit/gpn/TLV755P) | [DigiKey](https://www.digikey.com/en/products/detail/texas-instruments/TLV75533PDBVR/9356541) | [Exact library/native render passed](../../hardware/coupon/rev-a/power-library-audit.md); circuit pending |
| CC-state inverter | `SN74LVC1G04DBVR` | SOT-23-5; same USB-only 3.3 V rail | [TI product and ordering page](https://www.ti.com/product/SN74LVC1G04/part-details/SN74LVC1G04DBVR) | [DigiKey](https://www.digikey.com/en/products/detail/texas-instruments/SN74LVC1G04DBVR/385716) | [Exact library/native render passed](../../hardware/coupon/rev-a/power-library-audit.md); circuit pending |
| 3.3 V application rail | `TPS631000DRLR` | 8-pin `DRL` SOT-5X3 buck-boost | [TI datasheet](https://www.ti.com/lit/gpn/TPS631000) | [DigiKey](https://www.digikey.com/en/products/detail/texas-instruments/TPS631000DRLR/15965499) | [Exact library/native render passed](../../hardware/coupon/rev-a/power-library-audit.md); passives pending |
| LED rail | `TPS63020DSJT` | 14-pin `DSJ` VSON adjustable buck-boost | [TI datasheet](https://www.ti.com/lit/gpn/TPS63020) | [DigiKey](https://www.digikey.com/en/products/detail/texas-instruments/TPS63020DSJT/2263063) | [Exact library/native render passed](../../hardware/coupon/rev-a/power-library-audit.md); passives and thermal layout pending |
| Fuel gauge | `MAX17048G+T10` | 8-pin 2 × 2 mm TDFN | [Analog Devices datasheet](https://www.analog.com/media/en/technical-documentation/data-sheets/MAX17048-MAX17049.pdf) | [DigiKey](https://www.digikey.com/en/products/detail/analog-devices-inc-maxim-integrated/MAX17048G-T10/3758921) | [Exact library/native render passed](../../hardware/coupon/rev-a/power-library-audit.md); cell model and circuit review pending |
| Battery-current monitor | `INA232AIDDFR` | 8-pin `DDF`; proposed `A0 = GND`, address `0x40` | [TI datasheet](https://www.ti.com/lit/gpn/INA232) | [DigiKey](https://www.digikey.com/en/products/detail/texas-instruments/INA232AIDDFR/17748453) | [Exact library/native render passed](../../hardware/coupon/rev-a/power-library-audit.md); shunt and circuit pending |
| Active-high row decoder | `74HC4514PW,118` | 24-pin TSSOP; `E = HIGH` forces every row output low | [Nexperia product page and datasheet](https://www.nexperia.com/product/74HC4514PW) | [DigiKey](https://www.digikey.com/en/products/detail/nexperia-usa-inc/74HC4514PW-118/1230453) | [Exact library and native render passed](../../hardware/coupon/rev-a/row-library-audit.md); [row source captured](../../hardware/coupon/rev-a/row-capture.md); native circuit review and quote-time availability pending |
| P-channel row switch | `DMP2066LSN-7` | SC-59; sixteen required | [Diodes Incorporated datasheet](https://www.diodes.com/datasheet/download/DMP2066LSN.pdf) | [DigiKey](https://www.digikey.com/en/products/detail/diodes-incorporated/DMP2066LSN-7/1964690) | Exact library/native render passed and row source captured; switching test required |
| N-channel gate pull-down / small switch | `2N7002K-7` | SOT-23; row level shift and candidate ILIM branch switch | [Diodes Incorporated product page](https://www.diodes.com/part/view/2N7002K) | [DigiKey](https://www.digikey.com/en/products/detail/diodes-incorporated/2N7002K-7/1934378) | Exact library/native render passed and row source captured; 3.3 V row use requires review and measurement |
| USB D+/D− and CC ESD | `TPD4E05U06DQAR` | Four 0.5 pF channels in 10-pin `DQA` USON; place at receptacle | [TI product and ordering page](https://www.ti.com/product/TPD4E05U06/part-details/TPD4E05U06DQAR) | [DigiKey](https://www.digikey.com/en/products/detail/texas-instruments/TPD4E05U06DQAR/3996774) | [Exact library/native render passed](../../hardware/coupon/rev-a/power-library-audit.md); routing and clamp review pending |

The driver draft selects `ERJ-2RKF3922X` (39.2 kΩ) for IREF and `GRM155R71C104KA88D` (100 nF) for local decoupling, plus four `ERJ-2RKF1003X` 100 kΩ input pull-downs. The row audit adds `ERJ-2RKF1001X` (1 kΩ) as the P-MOSFET source-to-gate pull-up and reuses the 100 kΩ part for logic defaults. The controller capture adds `ERJ-2RKF1002X`, `ERJ-2RKF22R0X`, `ERJ-2RKF4990X`, `GRM188R60J106ME47D`, active `GRM155C71A105KE11D` and `EVQP7J01P`; its record controls values and use. The VBUS protection device, fuse strategy, regulator inductors/capacitors, current shunt and remaining thermal/layout values remain open. They must not be inferred from this short list.

## Mechanical interfaces and RF

| Function | Exact candidate | Evidence | State |
|---|---|---|---|
| USB-C receptacle | `USB4505-03-0-A` by GCT; USB 2.0, mid-mount with 1.0 mm connector offset, 0.80 mm recommended PCB thickness and through-hole shell stakes | [GCT product page and drawings](https://gct.co/connector/usb4505), [DigiKey](https://www.digikey.com/en/products/detail/gct/USB4505-03-0-A/15283201) | [Draft library/native render passed](../development/usb-connector-review-bf1627c.md); cutout, stack-up/process and case model pending; [final-grid edge screen](../../mechanical/usb-led-edge-screen-2026-09-26.md) |
| Battery board header | `BM03B-ACHFKS-GACN-ETF` | [JST ACHF family](https://www.jst-mfg.com/product/detail_e.php?series=627), [DigiKey](https://www.digikey.com/en/products/detail/jst-sales-america-inc/BM03B-ACHFKS-GACN-ETF/5272484) | Interface candidate |
| Battery cable housing | `ACHFR-03V-H` with `SACHF-003GAC-P0.2` contacts and AWG 28 wire | [JST ACHF family](https://www.jst-mfg.com/product/detail_e.php?series=627), [DigiKey housing](https://www.digikey.com/en/products/detail/jst-sales-america-inc/ACHFR-03V-H/5272189) | Interface candidate; pack vendor must build and document harness |
| 2.4 GHz antenna | `FXP75.07.0045B` by Taoglas; 5.9 × 4.1 × 0.24 mm FPC, 45 mm cable, I-PEX MHF I / U.FL-compatible plug | [Current Taoglas datasheet](https://www.taoglas.com/datasheets/FXP75.07.0045B.pdf), [DigiKey](https://www.digikey.com/en/products/detail/taoglas-limited/FXP75-07-0045B/4503578) | Candidate; documentation conflict and installed RF validation required |

The proposed pack conductor order is battery positive, NTC and battery negative, with NTC in the centre. Do not assign connector pin numbers or order a harness until the exact mating-view drawing and pack-vendor drawing have been overlaid and independently polarity-checked.

The current Taoglas revision F datasheet specifies 0.84 dBi peak gain at 2.4 GHz, below Espressif's 2.33 dBi certification limit. Some distributor metadata still reports 2.5 dBi for the same MPN, apparently from older documentation. Gate A therefore requires confirmation of the supplied antenna revision and its controlled datasheet; Gate B still tests the installed antenna with the battery, body, case and magnets present.

`FXP840.07.0055B` is rejected for this design because its manufacturer currently specifies 2.5 dBi peak gain at 2.4 GHz, above the module datasheet's 2.33 dBi limit. Its convenient outline is not sufficient reason to inherit avoidable certification uncertainty.
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

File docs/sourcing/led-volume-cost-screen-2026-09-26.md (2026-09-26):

<!-- SPDX-License-Identifier: CERN-OHL-S-2.0 -->

# LED count, traceable sourcing and project budget screen

2026-09-26. These are **representative listed prices**, not quotations or reservations. No purchase or choice of the final LED is approved. The 16 × 16 coupon compares two exact MPNs in equal halves; Gate B selects one for the five 48 × 16 final boards. Three coupon boards are intended to be assembled. The stated **USD 500–800 project target** includes coupon, five full PCBAs, cells, test tools and shipping; it excludes independent engineering review and case filament/design.

## Count before spares and assembly loss

| Quantity | Everlight `EAST10105RGBA0` | QT Brightek `QBLP1515A-RGB2A` | Combined |
|---|---:|---:|---:|
| Three assembled coupons, each 128 + 128 | 384 | 384 | 768 |
| Five 768-pixel finals if Everlight wins | 3,840 | 0 | 3,840 |
| Five 768-pixel finals if QT Brightek wins | 0 | 3,840 | 3,840 |
| **Total with Everlight final** | **4,224** | **384** | **4,608** |
| **Total with QT Brightek final** | **384** | **4,224** | **4,608** |
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

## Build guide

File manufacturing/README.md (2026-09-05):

<!-- SPDX-License-Identifier: CERN-OHL-S-2.0 -->

# Manufacturing releases

This directory will contain immutable coupon and badge fabrication releases. Each release must include Gerbers, drill files, BOM, placement file, assembly drawing, stack-up, factory firmware, test instructions, ERC/DRC/DFM evidence, SHA-256 manifest and known issues.

Generated files outside an approved release are ignored. No current directory is authorized for fabrication.

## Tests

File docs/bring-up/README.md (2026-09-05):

<!-- SPDX-License-Identifier: CERN-OHL-S-2.0 -->

# Bring-up records

Revision-specific bring-up procedures and logs belong here. A procedure must start with current-limited or otherwise fail-safe power, identify required equipment and define stop conditions before energizing VLED or connecting a LiPo cell.

No hardware has been brought up yet.

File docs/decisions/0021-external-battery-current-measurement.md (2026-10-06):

<!-- SPDX-License-Identifier: CERN-OHL-S-2.0 -->

# ADR 0021: Measure battery current externally during validation

- Date: 2026-10-06
- Status: **Accepted for coupon and final-badge capture; hardware validation pending**
- Supersedes: the production-intent INA232 battery-path monitor and approximately 10 mΩ shunt in the original project plan and the current-sensing row of proposed ADR 0018
- Retains: switched MAX17048 state-of-charge reporting, exact-pack charge/current limits, OFF-drain limit, runtime and charge-through measurements, hardware safeguards and independent Gate A

## Decision

Do not populate an on-board battery-current monitor or series measurement shunt on Coupon Rev A or the five intended final badges. The `INA232AIDDFR` library remains as historical candidate source, not a selected BOM item. Firmware reports battery voltage and state of charge from the switched MAX17048 while ON; it does not claim live battery-current or battery-power telemetry.

Measure battery charge/discharge and OFF leakage with a correctly polarized **inline instrument or protected-pack test harness** during coupon/final validation. Record instrument model, range, burden voltage, sample rate, pack and board revision with raw logs. Measure USB input separately. The measurement adapter must preserve the pack protection and charger NTC arrangement and must be checked against expected charge and discharge pulses before use. No battery-current limit, current-setting resistor or charger safeguard changes through this decision.

## Reason and consequence

The accepted product requirements call for measured runtime, USB limits, charge current and OFF leakage; they do not require signed current telemetry during normal playback. The MAX17048 estimates state of charge without a sense resistor. Removing the monitor also removes its power/injection review, dedicated shunt/drop/heat, Kelvin routing and I²C traffic. A [tight converter placement screen](../../mechanical/dual-row-package-screen-2026-10-06.md) fits all sixteen proposed dual-row package courtyards when the monitor's IC box is omitted; adding that box leaves one pair unplaced in the same heuristic. This is supporting area evidence, **not** proof of complete final-board fit. Charger/input support, display interlock, routing and the accepted row-stage decision still need engineering work.

The cost is loss of live signed battery-current/power readout and reliance on an inline instrument for validation. The runtime estimate in firmware must use measured board profiles, actual frames and the selected pack rather than pretend to read current. If live current telemetry later becomes a product requirement, reopen this decision with a revised layout, shunt error/current/thermal budget and powered-off behavior review before restoring the part.

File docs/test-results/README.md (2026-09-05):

<!-- SPDX-License-Identifier: CERN-OHL-S-2.0 -->

# Test results

Store raw logs, setup descriptions, photographs and concise result summaries by hardware revision. Never replace raw evidence with a hand-edited summary, and never claim a requirement passed without a reproducible test record.

No physical test results exist yet.

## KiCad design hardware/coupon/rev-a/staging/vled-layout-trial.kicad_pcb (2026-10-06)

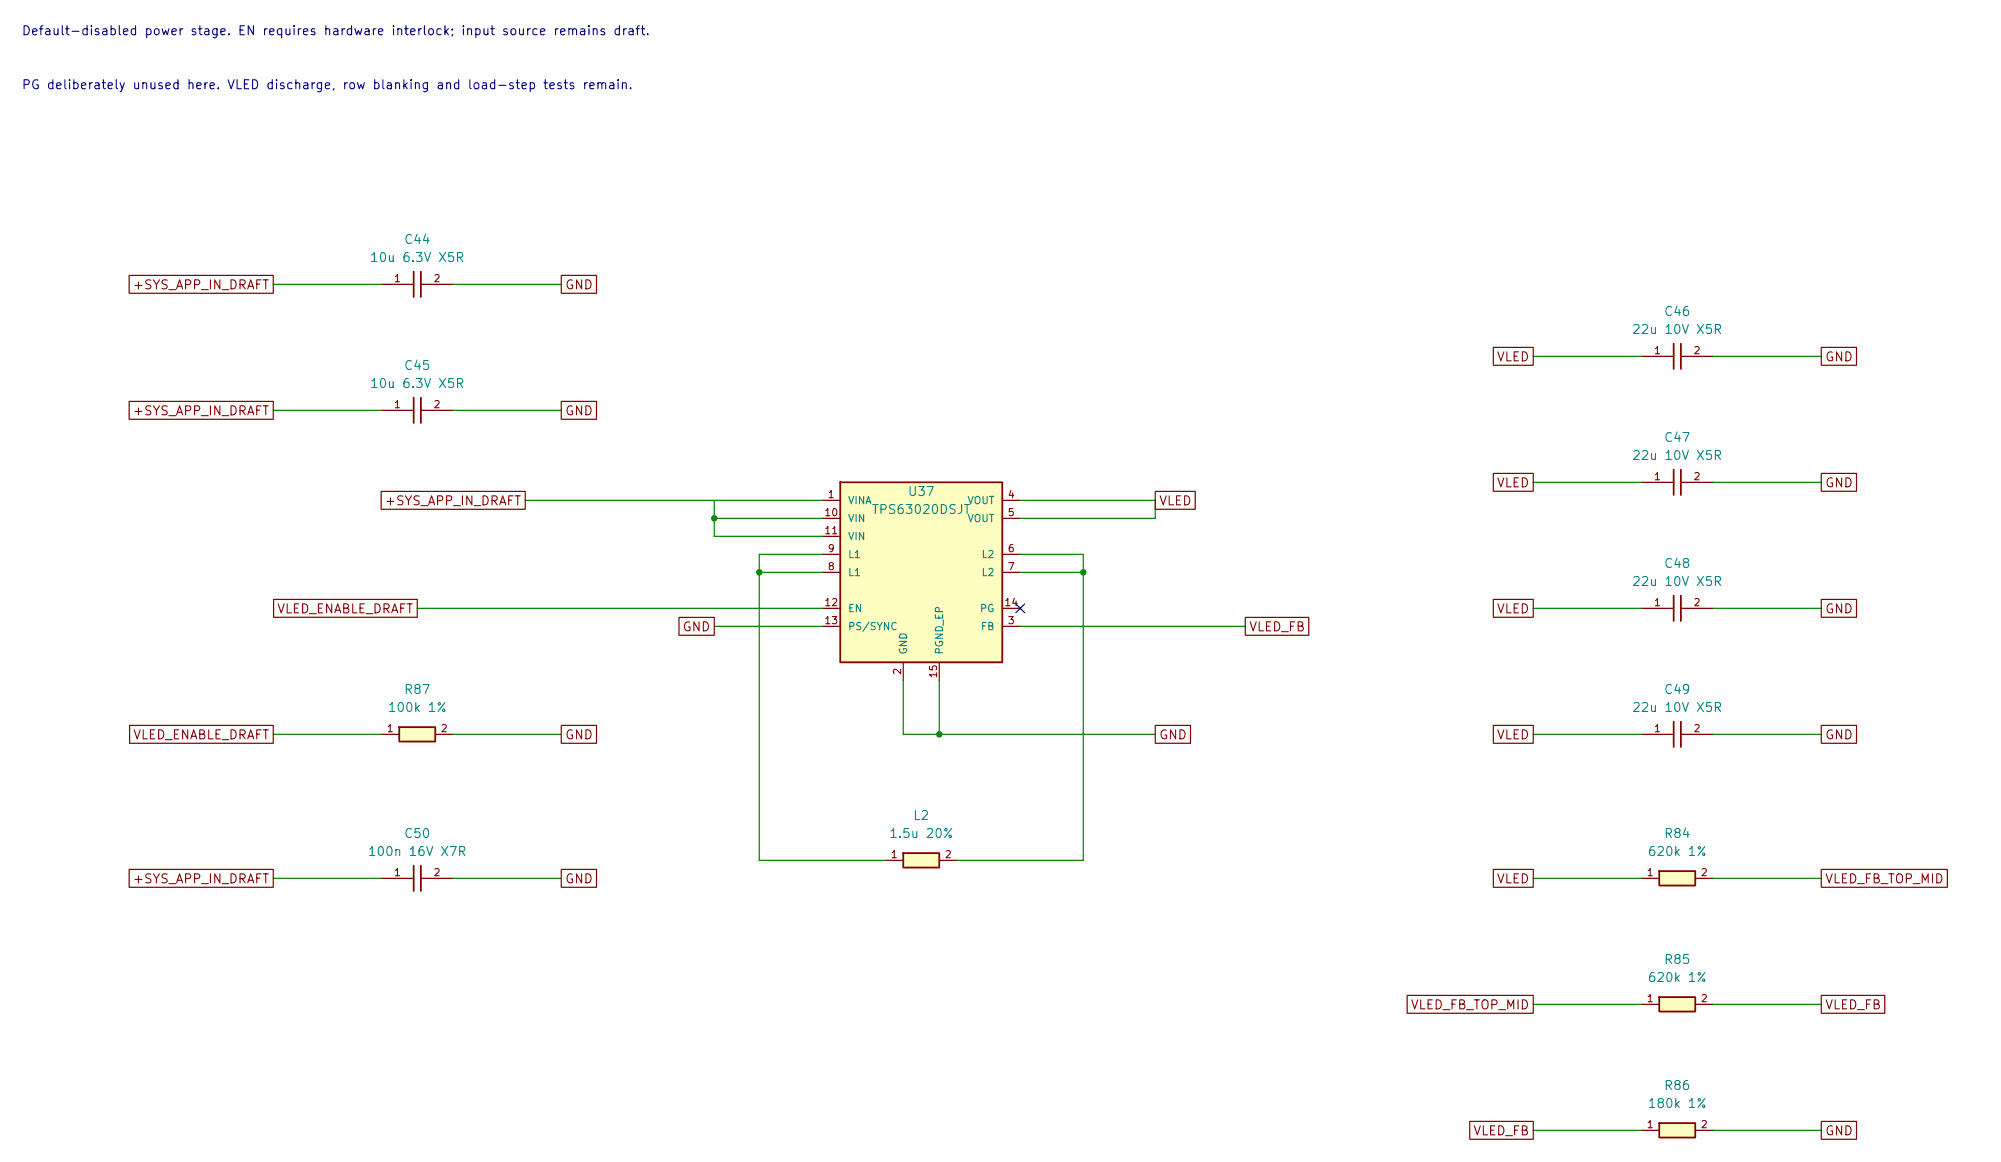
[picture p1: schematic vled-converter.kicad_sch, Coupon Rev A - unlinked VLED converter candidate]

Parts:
C44, C45: 10u 6.3V X5R; C_Murata_GRM18_0603; MPN GRM188R60J106ME47D
C46, C47, C48, C49: 22u 10V X5R; C_Murata_GRM18_0603; MPN GRM187R61A226ME15
C50: 100n 16V X7R; C_Murata_GRM15_0402; MPN GRM155R71C104KA88D
L2: 1.5u 20%; L_Murata_DFE252012P; MPN DFE252012P-1R5M=P2
R84, R85: 620k 1%; R_Panasonic_ERJ2_0402; MPN ERJ2RKF6203X
R86: 180k 1%; R_Panasonic_ERJ2_0402; MPN ERJ2RKF1803X
R87: 100k 1%; R_Panasonic_ERJ2_0402; MPN ERJ2RKF1003X
U37: TPS63020DSJT; VSON_TI_DSJ0014_4x3mm_P0.5mm_EP2.85x1.58mm; MPN TPS63020DSJT

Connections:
+SYS_APP_IN_DRAFT: C44.1, C45.1, C50.1, U37.1 (VINA), U37.10 (VIN), U37.11 (VIN)
GND: C44.2, C45.2, C46.2, C47.2, C48.2, C49.2, C50.2, R86.2, R87.2, U37.2 (GND), U37.13 (PS/SYNC), U37.15 (PGND_EP)
unnamed: L2.1, U37.8 (L1), U37.9 (L1)
unnamed: L2.2, U37.6 (L2), U37.7 (L2)
VLED: C46.1, C47.1, C48.1, C49.1, R84.1, U37.4 (VOUT), U37.5 (VOUT)
VLED_ENABLE_DRAFT: R87.1, U37.12 (EN)
VLED_FB: R85.2, R86.1, U37.3 (FB)
VLED_FB_TOP_MID: R84.2, R85.1

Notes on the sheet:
Default-disabled power stage. EN requires hardware interlock; input source remains draft.
PG deliberately unused here. VLED discharge, row blanking and load-step tests remain.

Board: 2 copper layers, 13 parts (0 on the bottom side), 8 nets, no tracks yet.

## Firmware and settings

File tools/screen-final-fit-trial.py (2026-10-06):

#!/usr/bin/env python3
# SPDX-License-Identifier: Apache-2.0
"""Build a to-scale, unconnected final-badge mechanical fit trial.

This deliberately does not produce a KiCad PCB or authorize fabrication.
"""

from __future__ import annotations

import importlib.util
import json
import math
import subprocess
import sys
import tempfile
from pathlib import Path
from xml.sax.saxutils import escape

ROOT = Path(__file__).resolve().parents[1]
OUT = ROOT / "mechanical/review"
for module_name, path in (
    ("preliminary_placement", ROOT / "tools/screen-preliminary-placement.py"),
    ("component_space", ROOT / "tools/screen-final-component-space.py"),
):
    spec = importlib.util.spec_from_file_location(module_name, path)
    module = importlib.util.module_from_spec(spec)
    assert spec.loader is not None
    sys.modules[module_name] = module
    spec.loader.exec_module(module)
layout = sys.modules["preliminary_placement"]
space = sys.modules["component_space"]

BOARD_W, BOARD_H = layout.BOARD_W, layout.BOARD_H
GRID = 0.25
UNDER_PACK_FPS = {"R_Panasonic_ERJ2_0402", "C_Murata_GRM15_0402"}
NTC_TARGET = {"x0": 51.0, "y0": 14.25, "x1": 55.0, "y1": 18.25}
DUAL_ROW_CANDIDATE = "U-DFN2020-6_TypeB_Diodes_DMC1229UFDB"


def overlap(a: dict, b: dict) -> bool:
    return a["x0"] < b["x1"] and a["x1"] > b["x0"] and a["y0"] < b["y1"] and a["y1"] > b["y0"]


def box(x: float, y: float, w: float, h: float) -> dict:
    return {"x0": round(x, 3), "y0": round(y, 3),
            "x1": round(x + w, 3), "y1": round(y + h, 3)}


def native_inventory() -> tuple[list[dict], dict]:
    with tempfile.TemporaryDirectory() as tmp:
        netlist = Path(tmp) / "coupon.xml"
        subprocess.run([space.kicad_cli(), "sch", "export", "netlist", "--format", "kicadxml",
                        "--output", str(netlist),
                        str(space.PROJECT / "rgb-badge-coupon.kicad_sch")],
                       check=True, stdout=subprocess.DEVNULL)
        return space.component_inventory(netlist)


def anchored_layout(inventory: list[dict]) -> tuple[list[dict], dict]:
    by_ref = {p["ref"]: p for p in inventory}
    base = layout.analyze()
    pack = base["battery_sensor_trial"]["lp503055_finished_body_max"]
    anchors: list[dict] = []

    def add(ref: str, category: str, x: float, y: float) -> None:
        p = by_ref[ref]
        anchors.append({"ref": ref, "category": category, "footprint": p["footprint"],
                        "box": box(x, y, p["width_mm"], p["height_mm"])})

    add("SW2", "top-edge control trial", 0.5, 0.3)
    add("SW1", "top-edge control trial", 10.5, 0.3)
    add("U2", "row decoder", 16.3, 0.45)
    # The external-antenna module is shifted left/down from the older rectangle
    # to expose a narrow strip for the row-stage bank. Its RF cable is unplaced.
    mcu_fp = layout.courtyard(layout.FOOTPRINTS / layout.PARTS["mcu"])
    anchors.append({"ref": "U3", "category": "MCU", "footprint": layout.PARTS["mcu"].removesuffix(".kicad_mod"),
                    "box": box(0.5, 9.25, mcu_fp.x1 - mcu_fp.x0, mcu_fp.y1 - mcu_fp.y0)})
    for i, rect in enumerate(base["rear_trial"]["drivers"], 1):
        anchors.append({"ref": f"U1-{i}", "category": "LED driver projection", "footprint": layout.PARTS["driver"].removesuffix(".kicad_mod"),
                        "box": rect})
    usb = layout.usb_courtyard(layout.courtyard(layout.FOOTPRINTS / layout.PARTS["usb"]))
    anchors.append({"ref": "J1", "category": "USB connector", "footprint": layout.PARTS["usb"].removesuffix(".kicad_mod"),
                    "box": vars(usb)})

    for n in range(16):
        add(f"Q{n+1}", "row P-MOS", 91.1 + (n % 2) * 3.55, 0.5 + (n // 2) * 3.8)
    nmos_xy = [(20.3, 9.3 + n * 3.4) for n in range(6)]
    nmos_xy += [(0.5, 5.1), (4.1, 5.1), (11.0, 4.2)]
    nmos_xy += [(x, y) for y in (0.5, 4.0, 23.0, 26.5) for x in (98.65, 102.2)]
    for n, (x, y) in enumerate(nmos_xy[:16]):
        add(f"Q{n+17}", "row N-MOS", x, y)

    for i, a in enumerate(anchors):
        for b in anchors[i+1:]:
            if overlap(a["box"], b["box"]):
                raise ValueError(f"Anchored courtyards overlap: {a['ref']} and {b['ref']}")
        r = a["box"]
        if r["x0"] < 0 or r["y0"] < 0 or r["x1"] > BOARD_W + 0.75 or r["y1"] > BOARD_H:
            raise ValueError(f"Anchor outside board/USB body guide: {a['ref']}")
        if a["ref"] != "J1" and overlap(r, pack):
            raise ValueError(f"Tall anchor intersects pack XY: {a['ref']}")
    return anchors, pack


def under_pack_trial(inventory: list[dict], pack: dict) -> list[dict]:
    by_ref = {p["ref"]: p for p in inventory}
    eligible = {p["ref"] for p in inventory if p["footprint"] in UNDER_PACK_FPS}
    placed: list[dict] = []
    def add(ref: str, x: float, y: float, category: str) -> None:
        p = by_ref[ref]
        r = box(x, y, p["width_mm"], p["height_mm"])
        if r["x0"] < pack["x0"] or r["y0"] < pack["y0"] or r["x1"] > pack["x1"] or r["y1"] > pack["y1"]:
            raise ValueError(f"Under-pack candidate outside pack: {ref}")
        if overlap(r, NTC_TARGET) or any(overlap(r, q["box"]) for q in placed):
            raise ValueError(f"Under-pack candidate collision: {ref}")
        placed.append({"ref": ref, "category": category, "footprint": p["footprint"], "box": r})
    # Keep the row-gate resistor pairs in two columns near the driver-side
    # edge. This is proximity intent, not a route-length qualification.
    for n in range(16):
        y = 1.2 + n * 1.875
        add(f"R{n+6}", 76.0, y, "row pull-up candidate")
        add(f"R{n+22}", 78.25, y, "row pull-down candidate")
    remaining = sorted(eligible - {p["ref"] for p in placed})
    for ref in remaining:
        candidate = by_ref[ref]
        found = False
        for yi in range(4, 116, 5):  # 1.0..28.75 mm, 1.25 mm pitch.
            for xi in range(104, 296, 9):  # 26..73.75 mm, 2.25 mm pitch.
                x, y = xi * GRID, yi * GRID
                r = box(x, y, candidate["width_mm"], candidate["height_mm"])
                if not overlap(r, NTC_TARGET) and all(not overlap(r, q["box"]) for q in placed):
                    add(ref, x, y, "other 0402 candidate")
                    found = True
                    break
            if found:
                break
        if not found:
            raise ValueError(f"Could not even place 0402 candidate in XY: {ref}")
    assert len(placed) == len(eligible) == 77
    return placed


def remaining_trial(inventory: list[dict], anchors: list[dict], under_pack: list[dict], pack: dict) -> tuple[list[dict], list[str]]:
    claimed = {p["ref"] for p in anchors + under_pack}
    parts = [p for p in inventory if p["ref"] not in claimed]
    nx, ny = int(BOARD_W / GRID), int(BOARD_H / GRID)
    occupied = [bytearray(nx) for _ in range(ny)]
    def mark(x: int, y: int, w: int, h: int) -> None:
        for yy in range(y, min(y + h, ny)):
            occupied[yy][x:min(x + w, nx)] = b"\x01" * max(0, min(x + w, nx) - x)
    for r in [pack, *[a["box"] for a in anchors]]:
        x0, y0 = math.floor(r["x0"] / GRID), math.floor(max(0, r["y0"]) / GRID)
        x1, y1 = math.ceil(min(BOARD_W, r["x1"]) / GRID), math.ceil(min(BOARD_H, r["y1"]) / GRID)
        mark(x0, y0, x1 - x0, y1 - y0)
    placed, unplaced = [], []
    for p in sorted(parts, key=lambda item: (-item["area_mm2"], item["ref"])):
        w, h = math.ceil(p["width_mm"] / GRID), math.ceil(p["height_mm"] / GRID)
        chosen = None
        for y in range(ny - h + 1):
            for x in range(nx - w + 1):
                if all(not any(occupied[yy][x:x+w]) for yy in range(y, y+h)):
                    chosen = x, y
                    break
            if chosen is not None:
                break
        if chosen is None:
            unplaced.append(p["ref"])
            continue
        x, y = chosen
        mark(x, y, w, h)
        placed.append({"ref": p["ref"], "category": "unrouted first-fit only", "footprint": p["footprint"],
                       "box": box(x * GRID, y * GRID, w * GRID, h * GRID)})
    return placed, unplaced


def candidate_package_minima(include_ina232: bool = False) -> list[dict]:
    names = [
        ("BQ24074 charger IC", "VQFN_TI_RGT0016C_3x3mm_P0.5mm_EP1.68mm", 1),
        ("TPS63020 VLED IC", "VSON_TI_DSJ0014_4x3mm_P0.5mm_EP2.85x1.58mm", 1),
        ("TPS259474 input-switch candidate", "VQFN_TI_RPW0010A_2x2mm_HotRod", 2),
    ]
    if include_ina232:
        names.append(("INA232 historical monitor comparison", "SOT23_THIN_TI_DDF0008A", 1))
    minima = []
    for label, fp, quantity in names:
        r = layout.courtyard(layout.FOOTPRINTS / f"{fp}.kicad_mod")
        minima.append({"label": label, "footprint": fp, "quantity": quantity,
                       "courtyard_mm": [round(r.x1-r.x0, 3), round(r.y1-r.y0, 3)]})
    return minima


def vled_candidate_package_minima() -> list[dict]:
    """Footprint-only inventory from the unlinked 13-part VLED sheet."""
    names = [
        ("L2", "L_Murata_DFE252012P", 1),
        ("C44-C45", "C_Murata_GRM18_0603", 2),
        ("C46-C49", "C_Murata_GRM18_0603", 4),
        ("C50", "C_Murata_GRM15_0402", 1),
        ("R84-R87", "R_Panasonic_ERJ2_0402", 4),
    ]
    result = []
    for label, fp, quantity in names:
        r = layout.courtyard(layout.FOOTPRINTS / f"{fp}.kicad_mod")
        result.append({"label": label, "footprint": fp, "quantity": quantity,
                       "courtyard_mm": [round(r.x1-r.x0, 3), round(r.y1-r.y0, 3)]})
    return result


def connector_envelope_screen(anchors: list[dict], placed: list[dict], pack: dict) -> dict:
    """Try an illustrative mated side-entry PH pocket, not a footprint/land audit."""
    sizes = [(8.0, 9.6), (9.6, 8.0)]
    grouped = [pack, *[p["box"] for p in anchors]]
    occupied = [*grouped, *[p["box"] for p in placed]]
    counts = []
    for w, h in sizes:
        fits_grouped = fits_all = 0
        for yi in range(round((BOARD_H - h) / GRID) + 1):
            for xi in range(round((BOARD_W - w) / GRID) + 1):
                candidate = box(xi * GRID, yi * GRID, w, h)
                if all(not overlap(candidate, other) for other in grouped):
                    fits_grouped += 1
                if all(not overlap(candidate, other) for other in occupied):
                    fits_all += 1
        counts.append({"envelope_mm": [w, h], "grid_mm": GRID,
                       "free_before_first_fit": fits_grouped, "free_after_first_fit": fits_all})
    return {
        "candidate_header": "JST S2B-PH-SM4-TB with PHR-2 housing; no pack termination selected",
        "status": "illustrative mated-connector pocket only; dimensions and direction are not an audited courtyard",
        "placements": counts,
        "omits": ["wire bend", "strain relief", "case wall", "routing", "mounting hardware"],
    }


def connector_first_trial(inventory: list[dict], anchors: list[dict], under: list[dict], pack: dict) -> dict:
    """Move control/decoder, reserve connector, then repack row FETs and other parts."""
    fixed = [{**p, "box": dict(p["box"])} for p in anchors if not p["ref"].startswith("Q")]
    for p in fixed:
        if p["ref"] == "SW1":
            p["box"] = box(91.1, 0.3, 5.1, 3.5)
        elif p["ref"] == "U2":
            p["box"] = box(97.0, 23.5, 7.7, 8.3)
    pocket = {"ref": "BAT", "category": "battery connector pocket",
              "footprint": "illustrative 8x8 mm envelope; no audited footprint",
              "box": box(16.5, 0.5, 8.0, 8.0)}
    fixed.append(pocket)
    for i, p in enumerate(fixed):
        for q in fixed[i + 1:]:
            if overlap(p["box"], q["box"]):
                raise ValueError(f"Connector-first fixed boxes overlap: {p['ref']}, {q['ref']}")
        if p["ref"] != "J1" and overlap(p["box"], pack):
            raise ValueError(f"Connector-first fixed box intersects pack: {p['ref']}")
    occupied = [pack, *[p["box"] for p in fixed]]
    moved_rows = []
    for original in reversed([p for p in anchors if p["ref"].startswith("Q")]):
        r = original["box"]
        w, h = r["x1"] - r["x0"], r["y1"] - r["y0"]
        found = None
        for yi in reversed(range(int((BOARD_H - h) / GRID) + 1)):
            for xi in range(int((BOARD_W - w) / GRID) + 1):
                candidate = box(xi * GRID, yi * GRID, w, h)
                if all(not overlap(candidate, other) for other in occupied):
                    found = candidate
                    break
            if found:
                break
        if found:
            occupied.append(found)
            moved_rows.append({**original, "box": found})
    other, unplaced = remaining_trial(inventory, fixed + moved_rows, under, pack)
    refs = {p["ref"] for p in inventory}
    placed_refs = {p["ref"] for p in fixed + moved_rows + under + other} & refs
    if placed_refs & set(unplaced) or placed_refs | set(unplaced) != refs:
        raise ValueError("Connector-first footprint accounting failed")
    all_boxes = fixed + moved_rows + under + other
    for i, p in enumerate(all_boxes):
        for q in all_boxes[i + 1:]:
            if overlap(p["box"], q["box"]):
                raise ValueError(f"Connector-first courtyards overlap: {p['ref']}, {q['ref']}")
    return {"status": "connector-first XY trial only; no audited connector footprint, routing or vertical fit",
            "connector_pocket": pocket, "fixed_and_repacked": fixed + moved_rows,
            "row_fets_placed": len(moved_rows), "row_fets_required": 32,
            "under_pack_0402_candidates": under, "other_unrouted_first_fit": other,
            "unplaced_captured_refs": unplaced,
            "rearrangement": ["SW1 moved to top-right", "U2 moved to lower-right",
                              "battery connector pocket next to pack left end",
                              "row FETs repacked from bottom-left"]}


def dual_row_package_screen(inventory: list[dict], connector_first: dict, pack: dict,
                            include_ina232: bool = False) -> dict:
    """Check package area for a proposed dual N/P part; do not alter the circuit."""
    dual = layout.courtyard(layout.FOOTPRINTS / f"{DUAL_ROW_CANDIDATE}.kicad_mod")
    pair_w, pair_h = dual.x1 - dual.x0, dual.y1 - dual.y0
    fixed = [{**p, "box": dict(p["box"])} for p in connector_first["fixed_and_repacked"]
             if not p["ref"].startswith("Q")]
    # The decoder occupied the lower-right power area in the connector-first
    # trial. The upper-right edge clears the USB body and leaves a converter bay.
    for p in fixed:
        if p["ref"] == "U2":
            p["box"] = box(97.0, 0.5, 7.7, 8.3)
    occupied = [pack, *[p["box"] for p in fixed]]
    reservations = []

    def reserve_fixed(ref: str, category: str, footprint: str, x: float, y: float,
                      w: float, h: float, orientation_deg: int = 0) -> None:
        candidate = box(x, y, w, h)
        if x < 0 or y < 0 or candidate["x1"] > BOARD_W or candidate["y1"] > BOARD_H:
            raise ValueError(f"Fixed trial box outside board: {ref}")
        collisions = [other for other in occupied if overlap(candidate, other)]
        if collisions:
            raise ValueError(f"Fixed trial box overlaps: {ref} {collisions}")
        occupied.append(candidate)
        reservations.append({"ref": ref, "category": category, "footprint": footprint,
                             "orientation_deg": orientation_deg, "box": candidate})

    def reserve(ref: str, category: str, w: float, h: float, footprint: str) -> bool:
        for yi in reversed(range(int((BOARD_H - h) / GRID) + 1)):
            for xi in range(int((BOARD_W - w) / GRID) + 1):
                candidate = box(xi * GRID, yi * GRID, w, h)
                if all(not overlap(candidate, other) for other in occupied):
                    occupied.append(candidate)
                    reservations.append({"ref": ref, "category": category,
                                         "footprint": footprint, "box": candidate})
                    return True
        return False
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

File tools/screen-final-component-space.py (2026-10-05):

#!/usr/bin/env python3
# SPDX-License-Identifier: Apache-2.0
"""Screen captured coupon parts against a hypothetical 48x16 rear floorplan.

This is a coarse 2D packing/area test, not PCB placement, routing or DRC.
"""

from __future__ import annotations

import argparse
import importlib.util
import json
import math
import os
import subprocess
import sys
import tempfile
import xml.etree.ElementTree as ET
from collections import Counter
from pathlib import Path

ROOT = Path(__file__).resolve().parents[1]
PROJECT = ROOT / "hardware/coupon/rev-a"
LAYOUT_SCRIPT = ROOT / "tools/screen-preliminary-placement.py"
spec = importlib.util.spec_from_file_location("preliminary_placement", LAYOUT_SCRIPT)
layout = importlib.util.module_from_spec(spec)
assert spec.loader is not None
sys.modules[spec.name] = layout
spec.loader.exec_module(layout)

GRID_MM = 0.25
TRIAL_COMPONENT_GAP_MM = 0.25  # Each side; not a routing or assembly clearance rule.
TEST_PAD_RESERVATION_MM = 1.5  # 1.0 mm pad plus a provisional 0.25 mm each side.
DRIVER_FP = layout.PARTS["driver"].removesuffix(".kicad_mod")
LARGE_FPS = {layout.PARTS[k].removesuffix(".kicad_mod") for k in ("mcu", "usb", "driver")}


def kicad_cli() -> str:
    candidate = os.environ.get("RGB_BADGE_KICAD_CLI")
    if candidate:
        return candidate
    app = Path("/Applications/KiCad/KiCad.app/Contents/MacOS/kicad-cli")
    if app.is_file():
        return str(app)
    from shutil import which
    found = which("kicad-cli")
    if found:
        return found
    raise RuntimeError("KiCad CLI is needed to export the current schematic netlist")


def component_inventory(netlist: Path) -> tuple[list[dict], dict]:
    root = ET.parse(netlist).getroot()
    parts = []
    counts = Counter()
    for comp in root.findall("./components/comp"):
        ref = comp.attrib["ref"]
        fp = (comp.findtext("footprint") or "").split(":")[-1]
        if not fp:
            raise ValueError(f"{ref} has no footprint")
        counts[fp] += 1
        if fp.startswith("LED_") or fp in LARGE_FPS:
            continue
        if fp == "TestPoint_Pad_D1.0mm":
            width = height = TEST_PAD_RESERVATION_MM
            source = "1.0 mm pad with trial 1.5 mm square reservation"
        else:
            rect = layout.courtyard(layout.FOOTPRINTS / f"{fp}.kicad_mod")
            width, height = rect.x1 - rect.x0, rect.y1 - rect.y0
            source = "project-local F.CrtYd"
        parts.append({"ref": ref, "footprint": fp, "width_mm": width,
                      "height_mm": height, "area_mm2": round(width * height, 4), "source": source})
    return parts, dict(sorted(counts.items()))


def screen(parts: list[dict], counts: dict) -> dict:
    trial = layout.analyze()
    back = trial["rear_trial"]
    pack = trial["battery_sensor_trial"]["lp503055_finished_body_max"]
    usb = layout.usb_courtyard(layout.courtyard(layout.FOOTPRINTS / layout.PARTS["usb"]))
    fixed = {"lp503055_body": pack, "mcu": back["controller"],
             "drivers": back["drivers"], "usb_connector_courtyard": vars(usb)}
    board_area = layout.BOARD_W * layout.BOARD_H
    def area(box: dict) -> float:
        return (box["x1"] - box["x0"]) * (box["y1"] - box["y0"])
    pack_area = area(pack)
    usb_on_board = {"x0": max(0, usb.x0), "y0": max(0, usb.y0),
                    "x1": min(layout.BOARD_W, usb.x1), "y1": min(layout.BOARD_H, usb.y1)}
    fixed_area = area(back["controller"]) + sum(area(r) for r in back["drivers"]) + area(usb_on_board)
    free_area = board_area - pack_area - fixed_area
    small_area = sum(p["area_mm2"] for p in parts)

    # First-fit stress test with fixed large reservations and a small perimeter
    # around each remaining part. It ignores nets, thermal placement and routing.
    nx, ny = int(layout.BOARD_W / GRID_MM), int(layout.BOARD_H / GRID_MM)
    cells = [bytearray(nx) for _ in range(ny)]
    def occupy(x: int, y: int, w: int, h: int) -> None:
        for yy in range(y, min(y + h, ny)):
            cells[yy][x:min(x + w, nx)] = b"\x01" * max(0, min(x + w, nx) - x)
    for box in [pack, back["controller"], *back["drivers"], vars(usb)]:
        x0 = math.floor(box["x0"] / GRID_MM)
        y0 = math.floor(max(0, box["y0"]) / GRID_MM)
        x1 = math.ceil(min(layout.BOARD_W, box["x1"]) / GRID_MM)
        y1 = math.ceil(min(layout.BOARD_H, box["y1"]) / GRID_MM)
        occupy(x0, y0, x1 - x0, y1 - y0)
    placed, unplaced = [], []
    for part in sorted(parts, key=lambda p: (-p["area_mm2"], p["ref"])):
        w = math.ceil((part["width_mm"] + 2 * TRIAL_COMPONENT_GAP_MM) / GRID_MM)
        h = math.ceil((part["height_mm"] + 2 * TRIAL_COMPONENT_GAP_MM) / GRID_MM)
        chosen = None
        for y in range(ny - h + 1):
            for x in range(nx - w + 1):
                if all(not any(cells[yy][x:x + w]) for yy in range(y, y + h)):
                    chosen = (x, y)
                    break
            if chosen is not None:
                break
        if chosen is None:
            unplaced.append(part["ref"])
            continue
        x, y = chosen
        occupy(x, y, w, h)
        placed.append({"ref": part["ref"], "footprint": part["footprint"],
                       "x0": x * GRID_MM, "y0": y * GRID_MM,
                       "x1": (x + w) * GRID_MM, "y1": (y + h) * GRID_MM})
    return {
        "method": "2D courtyard-area lower bound and first-fit 0.25 mm grid stress test; not a PCB",
        "board_mm": [layout.BOARD_W, layout.BOARD_H],
        "assumptions": ["48x16 front LED array replaces the coupon's 256 mixed LEDs",
                        "three driver bodies replace the coupon's one driver body",
                        "all 151 other captured footprints are trialed on the rear outside the pack",
                        "only the LP503055 finished body is reserved; leads, PCM protrusion, connector and swelling are omitted",
                        "uncaptured charger, VLED, input protection and other final support parts are omitted"],
        "schematic_footprint_counts": counts,
        "fixed_boxes": fixed,
        "area_mm2": {"board": round(board_area, 2), "lp503055_body": round(pack_area, 2),
                     "mcu_three_drivers_usb": round(fixed_area, 2),
                     "free_after_fixed_boxes": round(free_area, 2),
                     "other_captured_courtyards_and_testpad_reservations": round(small_area, 2),
                     "remaining_before_clearance_routing_or_missing_parts": round(free_area - small_area, 2)},
        "packing_trial": {"component_gap_each_side_mm": TRIAL_COMPONENT_GAP_MM,
                          "placed_count": len(placed), "unplaced_count": len(unplaced),
                          "unplaced_refs": unplaced, "placed": placed},
        "inventory": parts,
    }
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

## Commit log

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2026-09-06 Add Coupon Rev A KiCad scaffold
    [rgb-badge-coupon.kicad_sch]
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2026-09-06 Record KiCad 10 GUI round trip (#1)
    Capture the canonical KiCad 10.0.6 project settings after a successful macOS GUI save, ignore KiCad local history, and record the validation result.
2026-09-06 Add controlled Coupon Rev A LED libraries
    Transcribe exact-MPN symbols and manufacturer land patterns for the two LED finalists, document the QBLP1515 checkerboard placement decision, and add deterministic pin/pad/geometry plus KiCad SVG-exp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
2026-09-06 Improve LED library readability and split review exports
    Remove redundant symbol body text and widen the boxes to separate the green-cathode and anode labels. Keep electrical pin identities and both footprint files unchanged. Export numbered fabrication and copper-only views separately, require all six SVGs, and add seven stub-CLI regression tests. Record the owner's earlier KiCad 10.0.6 check while leaving the corrected render and independent review pending.
    [check-led-libraries.py, test_check_kicad.py]
2026-09-06 Finish LED pad-number review and preserve KiCad evidence
2026-09-07 Capture the 256-LED coupon matrix and verify pin-to-net assignments
    [matrix-r00-c00.kicad_sch, matrix-r00-c08.kicad_sch, matrix-r08-c00.kicad_sch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]
2026-09-07 Fix matrix label direction and record native KiCad validation
    [matrix-r00-c00.kicad_sch, matrix-r00-c08.kicad_sch, matrix-r08-c00.kicad_sch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]
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2026-09-07 Capture TLC59581 coupon driver and audit its current reference and footprint
    [driver.kicad_sch, rgb-badge-coupon.kicad_sch]
2026-09-08 Connect driver readback to a probe pad and record native ERC finding
    [driver.kicad_sch]
2026-09-08 Record successful native driver ERC netlist and drawing review
2026-09-08 Audit Coupon Rev A row-selection libraries (#5)
    Add and verify the exact row-decoder, MOSFET, resistor symbols and audited footprints. Record the passing owner KiCad 10.0.6 native export, ERC, XML and visual review while preserving Gate A, DFM and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
2026-09-08 Capture Coupon Rev A row selectors
    [matrix-r00-c00.kicad_sch, matrix-r00-c08.kicad_sch, matrix-r08-c00.kicad_sch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]
2026-09-08 Restore complete matrix sheets after branch transfer
    [matrix-r00-c00.kicad_sch, matrix-r08-c00.kicad_sch]
2026-09-09 Capture Coupon Rev A ESP32-S3 controller (#7)
    Validated with the owner’s native KiCad 10.0.6 run at d56e1aa; independent Gate A still gates fabrication.
    [controller.kicad_sch, rgb-badge-coupon.kicad_sch]
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2026-09-09 Fix power footprint copper and stencil defects found in native review
    [check-power-libraries.py]
2026-09-10 Accept corrected power-library review and clear row schematic title block
    [driver.kicad_sch, matrix-r00-c00.kicad_sch, matrix-r00-c08.kicad_sch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]
2026-09-10 Reject unqualified USB input network and record replacement assessment
    [check-power-design.py]
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2026-09-15 Record native review of replacement power libraries
    [check-power-design.py]
2026-09-15 Reserve USB auxiliary current and define hardware permission logic
2026-09-16 Capture conditioned USB permission gates and verify their actual wiring
    [rgb-badge-coupon.kicad_sch, usb-conditioning.kicad_sch, usb-permission.kicad_sch]
2026-09-17 Capture USB detection and switched data path after native logic review
    [controller.kicad_sch, rgb-badge-coupon.kicad_sch, usb-conditioning.kicad_sch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]
2026-09-17 Review native USB capture and add staged logic-rail supervision
    [usb-conditioning.kicad_sch, usb-interface.kicad_sch, usb-permission.kicad_sch]
2026-09-17 Qualify precision resistor selection and record supervisor review
2026-09-18 Accept native resistor review and screen charger actuator candidates
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2026-09-19 Simplify charging to Type-C-only fixed-current policy
    [usb-conditioning.kicad_sch, usb-interface.kicad_sch, usb-permission.kicad_sch]
2026-09-19 Terminate conditioned OUT2 on its diagnostic test pad
    [usb-conditioning.kicad_sch]
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2026-09-19 Correct USB voltage envelope and widen USB logic supply headroom
    [usb-interface.kicad_sch]
2026-09-24 Record native input-library and regulator review at bad43fa
2026-09-25 Assess charger input gating as a simpler permission boundary
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2026-09-25 Align project plan gate and mass budget with active charging policy
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2026-09-25 Screen candidate packs against 80 percent charge target
2026-09-25 Record minimum modeled capacity and excluded wide pack
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2026-09-25 Correct OVLO recovery interpretation at 5 volts
2026-09-25 Screen wider OVLO window against charger pin limits
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2026-09-26 Screen passive charger EN1 network against output and leakage limits
2026-09-26 Screen badge enclosure width and battery thickness margins
2026-09-26 Screen LED volume and budget against traceable supplier prices
2026-09-26 Screen final LED grid against USB cutout and board thickness
2026-09-26 Screen charger dissipation at USB high voltage and pack current corners
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2026-09-26 Stage switched MAX17048 gauge and audited pull-ups
    [gauge.kicad_sch, rgb-badge-coupon.kicad_sch]
2026-09-27 Space gauge ground labels after native render review
    [gauge.kicad_sch]
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2026-09-30 Shortlist exact 3.3 V feedback resistors and drift corners
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2026-09-30 Correct 3V3 feedback resistor order codes
    [check-3v3-feedback-libraries.py]
2026-09-30 Normalize Panasonic ERJ order codes across coupon
    [controller.kicad_sch, driver.kicad_sch, gauge.kicad_sch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]
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2026-10-05 Stage exact-part 3V3 converter candidate with source pin checks
    [3v3-converter.kicad_sch]
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2026-10-05 Review native 3V3 candidate and repair drawing spacing
    [3v3-converter.kicad_sch]
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2026-10-05 Connect provisional app switch and 3V3 converter
    [3v3-converter.kicad_sch, app-control.kicad_sch, driver.kicad_sch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]
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2026-10-05 Correct battery-over-board placement assumption
    [screen-final-component-space.py]
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2026-10-06 Stage default-disabled VLED converter candidate
    [vled-converter.kicad_sch]
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2026-10-06 Stage tighter VLED layout and simplify battery-current measurement
    [vled-layout-trial.kicad_pcb]
2026-10-06 Record native VLED placement DRC and resolve CLI context
    [vled-layout-trial.kicad_pcb]
2026-10-06 Add partial native VLED routing geometry study
    [vled-routing-trial.kicad_pcb]
2026-10-06 Reorder VLED feedback divider in fit and KiCad trials
    [vled-layout-trial.kicad_pcb, vled-routing-trial.kicad_pcb]
2026-10-07 Screen lower fixed USB input limit for power architecture
    [analyze-power-architecture.py]
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2026-10-07 Stage charger EN2 local clamp candidate and DC screen
    [charger-en2-candidate.kicad_sch]
2026-10-09 Screen connectorized pack fit and refine EN2 clamp candidate
    [charger-en2-candidate.kicad_sch]
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2026-10-10 Connect battery-facing charger temperature subcircuit
    [charger-temperature.kicad_sch, rgb-badge-coupon.kicad_sch]
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2026-10-10 Connect provisional BQ24074 charger core to battery NTC
    [app-control.kicad_sch, charger-core.kicad_sch, rgb-badge-coupon.kicad_sch]
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2026-10-13 Trial routed USB VBUS entry and E0 bulk output on coupon board
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2026-10-14 Record LED column routing collision probe
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2026-10-16 Reserve 1010 LED escapes and route trial row buses at 114 mm
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2026-10-23 Record bounded ground searches and rejected R36 colour replacement
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2026-10-27 Reduce routing study to 71 opens with verified local track replacements
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2026-10-28 Connect UART probe through an exact source-chain rework at 62 opens
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2026-10-30 Correct all six exact Murata capacitor lands and preserve 59-edge routing
2026-10-30 Join gauge switch supply at 58 opens and correct printed switch terminals
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2026-10-30 Catalog converter rework contacts and clarify capacitor approval hold
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2026-10-31 Record short VLED switching-path feasibility without selecting a moved power stage
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2026-11-01 Record full VLED stage restoration with preserved source groups and short ground return
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2026-11-05 Review complete converter power stages and prioritize bounded corrections
2026-11-06 Correct U36 local stage and enforce provisional HDI constraints
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2026-11-10 Join shunt ground with exact R11 leaf clearance at 35 opens
2026-11-12 Correct RSE flip-flop pin mapping and retain 35-open routing
2026-11-12 Refresh pin inventory fingerprints after corrected RSE capture
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2026-11-12 Bound fixed thermistor transfer and CC1 supply restoration studies
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2026-11-12 Record coupled gauge supply restoration and retention failures

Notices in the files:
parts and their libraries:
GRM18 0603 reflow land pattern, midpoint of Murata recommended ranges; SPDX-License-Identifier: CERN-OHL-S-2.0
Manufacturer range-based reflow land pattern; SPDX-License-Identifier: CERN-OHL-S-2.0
